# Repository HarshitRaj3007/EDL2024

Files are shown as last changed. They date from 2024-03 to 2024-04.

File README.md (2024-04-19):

# EDL2024
Repository for our EDL project in year 2024. RRAM Characterization using FPGA.

This repository contains the PCB design files of all the three modules (Main PCB, Resisitive crossbar array, Power PCB), HDL code, Python code used for GUI, and PCB enclosure design files.

There are 3 files for documentation:
1. Documentation for programming, laptop-FPGA interface & GUI
2. Documentation for PCB
3. Documentation for Testing(mainly Analog)

**HDL files**: EDL_merged_code encapsulates all the HDL code and the .py files for GUI. folder has a readme file that holds detailed information about the directory.

**PCB files**: MiniCircuit contains KiCAD files for a scaled-down version of the PCB intended for testing, FinalCircuit contains design files of the main PCB module, ResistiveCrossbar contains design files for a 3 $\times$ 3 resistive crossbar array and PowerConverter has the design files for the power PCB which was intended to power the entire module from wall supply of 230 V AC. 

**CAD files**: A basic PCB enclosure which can be fabricated via laser cutting can be found in the Enclosure_Fusion360.dxf file. Couldn't add the .stp file for the reference 3D design of the complete circuit due to file size restrictions in GitHub. 

**Operating Procedure**

Since the power PCB module we designed turned out to be faulty, we had to use power banks instead to supply $\pm$ 5 V, which have to connected appropriately to the corresponding pins in the main PCB module. The final design is highly user-friendly and all one needs to do after this step is to provide the parameters under which the characterization is to be executed: amplitude of the input pulse, the location of the resistor in the array, the mode of operation (RD/WR) and the requisite $R_{sense}$ location. The GUI displays both the input and output waveform for a pulse width of 100 $\mu s$, along with the estimated value of the resistance.

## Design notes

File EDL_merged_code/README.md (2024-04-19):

EDL 2024 P16-MON-08
 An FPGA-instrument for RRAM characterization
with on-board oscilloscope

Documentation 
for programming, laptop-FPGA interface & GUI

-Deshpande Varad Shailesh
(for whole S/W)
-21d070024

-Harshit Raj(for GUI) 
20d070033

Salient Features:
Microsecond pulsing: Square pulse as small as 100us can be achieved
ADC sampling happens at a rate around 80-100 ksps (kilo samples per second)
Communication of FPGA with laptop happens through the same USB cable used to dump code from laptop to FPGA and no other modules are required. 
A GUI on which pulse value, resistor selection and R_sense selection can be carried out. Upon hitting the send button, all necessary signals are sent out to the board, which returns the voltage waveforms for V1 and V2; These are, in turn, displayed along with the calculated value of resistance. 
Future scope: Can very easily implement pulse width value selection and intelligent R_sense selection since we have kept provisions in place for these.

Code structure:
	Entire code is essentially contained in these 5 parts
EDL_merged_code.v: The file that implements driver for Intel Avalon interface to initiate uart jtag communication with laptop and instantiates the entity for ADC & DAC.
ADC_DAC_control.vhd: This file has drivers for ADC(MCP3008) and DAC(MCP4921) and also the control logic for storing samples from the ADC, receiving square wave amplitude to the DAC.
uart_jtag(folder): This has Intel’s IPs for the avalon interface. Cannot be changed directly, any manipulation is performed through the entity declared in the .qsys file.
New_gui.py: Running this file launches the GUI.
helper.py: To encode the chosen resistor in the network into control signals to be sent to the FPGA.

Some important points to note:
Quartus needs to be installed on the device and dumping of .sof file from the computer to the FPGA must be sorted. The device must have any latest version of python installed and the Intel jtag uart python wrapper installed : https://pypi.org/project/intel-jtag-uart/, credits to Tom Verbeure.
Everytime before running the setup, the .sof file needs to be dumped from the Programmer in Quartus to the FPGA by pressing the ‘Start button’. Once this is done, the GUI can be launched after ensuring that the power supply to the PCB is at proper values of +5 and -5V. This needs to be done for performing every experiment. This is because there is some problem in resetting the FSM to the initial state, and requires some debugging the state 130;
The current code sends out a square wave to have ease of visualization, this can be changed to send a pulse by suitably modifying code in ADC_DAC_control.vhd
Provision has been made to send a pulse width from the laptop to the FPGA with proper encoding in the FSM. Changes would be required to be made in new_gui.py and both the HDL files.
Functionality for -5V reset has been provided on PCB and in the code, but needs to be tested, and would involve sending +9V and -5V to the 4066 switches on board the PCB.

Reason why minor things remain to be given a final touch:
Honestly, I feel looking back that it was way too much work for one person. Especially since programming an FPGA is generally more challenging than programming a microcontroller and that I have very little experience working with a physical FPGA. I was not familiar with verilog and had to learn this on the go. Intel’s IP files were in verilog and to implement the driver in vhdl, I would anyway need to experiment with verilog, and since attempts at doing this in vhdl failed, I had to:
Learn verilog on the go
Write driver for Intel Avalon interface in verilog while experimenting with how it worked
Since the drivers for ADC and DAC were already written in VHDL, I found a way to compile both .v and .vhd files together instead of writing driver files from scratch in verilog. 
Had I taken VLSI Design Lab in this 6th semester, my life would have been much much easier.

Sampling a clipped sine: something I’m very happy about. ADC samples correctly, and sends data correctly to the laptop through jtag uart.

Challenges in development:
“Every little signal, every state, every byte destined to be transferred had to be rehearsed with a dance on the on-board FPGA LEDs. I had kept a portable lab handy with a breadboard, some jumpers, a trim pot and a DMM to test my ADC, DAC codes just about anywhere, without a DSO.”

ADC(MCP3008) and DAC(MCP4921): Took me nearly 1.5 months to make reliable drivers for these. I also wrote drivers for AD5443 and ADS7223. The code might appear somewhat complicated due to its lengthiness. However, it is simple to understand with a counter depicting every clock cycle in the respective timing diagrams.
Talking to the FPGA from a laptop using the pre-existing jtag channel which is used to dump code to the FPGA. I followed this tutorial : https://tomverbeure.github.io/2021/05/02/Intel-JTAG-UART.html by Tom Verbeure, which involved writing a driver on the FPGA side that communicates with the Intel Avalon interface,and another of his guide: https://tomverbeure.github.io/2021/05/08/Write-Your-Own-C-and-Python-Clients-for-Intel-JTAG-UART-with-libjtag_atlantic.html for the python side.
The interface is very intricate and difficult to grasp. I had to spend a great deal of time experimenting with this, changing how every enable signal affected transmission and reception with every clock cycle. 
	To ensure reliability, I had to encode every byte transferred to denote its purpose or its place in the sequence. For example, a byte written from the laptop stays in the Intel avalon interface for an unknown amount of time, and the receiving end at the FPGA keeps receiving this byte for an unknown amount of time, until it changes due to transmission of a subsequent byte from laptop. To ensure that the byte being read is indeed the subsequent one and not the previous, I had to toggle the top 2 MSBs of the byte and use this information in conjunction with the knowledge of the present state in the FSM to ensure communication. This “jugaad” if you permit, had to be done due to a lack of time, lack of proper access, and guidance to the Intel Avalon interface.
Mixed synthesis of verilog and vhdl files: I had to again guess, try step-by-step these things from the basics for having a poor background in this matter. From passing a single signal to the vhdl entity instantiated in the verilog file to sending large vectors, clock and trigger signals between files.
Overall debugging: The painful feeling of realising that something was not working despite being careful. Mostly used LEDs to figure out what went wrong by mapping the signal to the LED output onboard the FPGA. Very limited information accessible at one instant, coupled with the time it took to compile the code(~1 min) made it a very lengthy process.

GUI Operating Instructions (and some points on its working):

CHECK First compile the quartus project and dump the code to FPGA using programmer
Then run new_gui.py to open the GUI. It is in the folder EDL_merged_code. It has a dependent file — helper.py which contains the logic for control signals and it should be in the same folder for the GUI to run properly. The sections to fill follow below.
Pulse amplitude (V) — The amplitude of the pulse to give out. Just write a floating point number which is at least 1.5V away from the max supply of the opamps (supplies connected to the -15V and +15V power headers). For example: 2.56
Array location (i,j) — The coordinates of the memristor/resistor to choose for programming/reading in the crossbar. Don’t fill in the brackets. For example: 2,3
Mode — To decide the mode of operation. It should be either: Read, Write or Reset. Note: for resetting, there should be a negative voltage at the -5V power header. Only Read has been tested extensively.
R Sense (2-6) — To choose which sense resistor to use (only in Read mode). Just enter an integer between 2 and 6 (both inclusive). For example: 3. The below table shows the corresponding resistance value:

R Sense
Resistance (Ω)
2
1M
3
300k
4
100k
5
30k
6
12k

Press the Send button after entering the above fields. The resistance value will be calculated in the Resistance (kOhm) field. The input and output waveforms, V1 and V2 will be plotted on the graph above the entry fields (only in Read mode will it be accurate). Note: we have accidentally swapped the labels V1 and V2 in the plot. The higher amplitude will be V1.
To re-run with new values, close the window and re-program the FPGA using the Quartus programmer. Then again run the new_gui.py file. We know it's not ideal but the FPGA code at the moment doesn’t support looping back reliably. The GUI instead does support it, in case it is to be used in the future.

Control Signals:

Controls 1 through 8 correspond to the Switches 1 through 8 as in the paper. 1 is for writing and 2 through 6 are the sense resistors. 7 and 8 are for connection to the ADC.
Controls 9A and 9B correspond to the Switch 9 in the paper. It was an SPDT switch but since we used SPST switches, we need two control signals and had to split it. 9A and 9B should always be the complement of each other. The same happens in Switch 10
VtXY corresponds to the vertical crossbar line X, and Y is either A or B, similar to the above point.
HzXY is similarly the horizontal crossbar line X, and Y is either A or B.
To choose a location say 2,3 — set Hz2A = 1 and Hz2A = Hz3A = 0, Vt1A = Vt2A = 1 and Vt3A = 0 (B will always be the complement of corresponding A). Hence, in HzXA, only one is set 1 whereas in VtXA, only one is set 0.
Read/Write and Reset is self explanatory and set 1 when doing that task.

For the FPGA connection, connect it to header GPIO 00  such that the entire FPGA lies away from the main PCB. The pins 1 and 3 in DE0-nano were read only so we had to short it to empty pins to ensure we could write on it. The exact pin mapping is given below with pin 1 shorted to pin 19 and pin 3 to pin 21 using wire on the PCB.

Note: The pins 11,12,29,30 are power and ground pins and so cannot be programmed. This is ensured in the mapping.

Due to the lack of time, PCB Lab didn’t print our silkscreen. To identify the pin 1 in the FPGA header, look at the main PCB such that the RRAM connection header and the power header are towards your side with the FPGA header towards the right. In this orientation, the above image exactly matches the FPGA headers. So the bottom right pin will be pin 1.

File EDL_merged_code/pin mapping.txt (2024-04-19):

ADC:
GPIO_033 - B12 - ch select ADC

GPIO_024 - C9 - reset_ADC
GPIO_025 - D9 - Din_ADC
GPIO_026 - E11 - Dout_ADC
GPIO_027 - E10 - CS_ADC
GPIO_028 - C11 - Sclk_ADC

DAC:
GPIO_00  - D3 - CS_DAC
GPIO_01 - C3 - LDAC_DAC
GPIO_02 - A2 - SCK_DAC
GPIO_03 - A3 - SDI_DAC
GPIO_04 - B3 - reset_DAC

MSB:
t1-something 
t2-correct
LSB:
t1-correct
t2-=MSB whole byte

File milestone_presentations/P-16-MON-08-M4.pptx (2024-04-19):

## An FPGA-Based Instrument for RRAM Characterization

EE 344 - Electronic Design Lab

Milestone 4

MON - 08

Debasish Panda [21d070021]
Deshpande Varad Shailesh [21d070024]

Grampurohit Shreyas Jayant [21d070029]
Harshit Raj [20d070033]

## Project Summary

We present a compact, FPGA-based implementation for characterizing RRAM (Resistive Random Access Memory) crossbar arrays which is intended to aid researchers in their study of RRAM.
- Read capability
- Write capability
- Interface available at laptop through same USB cable

## Demo Video

Link to the demo video - Demo (https://drive.google.com/drive/folders/1pQi-J_PCMW7gSlmyvDTKhVnrJv0H3NYU?usp=drive_link)

## Methodology

PCB Design and print

Design simplified circuit

Breadboard, test

Graphical User Interface

Understand reference Analog Design

[jtag uart] FPGA & Laptop link

DAC, ADC drivers

Final Circuit Design

PCB Design and print

Breadboard, test

CAD

Design ideal circuit

## Challenges faced and their solutions

Challenges | Solutions | Remarks
MAX4737 not dual supply | CD4066 | Successful
Only SPST switches but needed SPDT as well | Connected two in parallel and gave opposite control signals | Successful
DAC ESD issue | Use different DAC | Successful
ADC damage | ESD damage or excessive voltage sent during testing | Unsuccessful
100 kHz input on THT resistor lead to slewing output (like RC circuit) | Used SMD resistors to reduce capacitance, but it still had the issue | Unsuccessful
Negative voltage supply issue | External power bank | Successful
Designed a –1/2 gain instead of a +1/2 requirement in Simplified PCB | Changed the design in the Final PCB | Successful

## Challenges faced and their solutions

LM6172 OpAmp IC overheating on Simplified PCB | Searched for shorting issues | Unsuccessful
Footprint of RRAM IC wasn’t known | Made the design modular by providing a header output | Successful
Short in a trace with the ground plane in printed Final PCB | Searched for it under a microscope and cut it | Successful
Two header pins of FPGA routed on PCB were read only | Shorted it with unassigned header pins | Successful
Xen10 real time communication issue and lack of header pins | Used DE0-Nano | Successful
DE0-Nano UART JTAG/array issue | Limited documentation, very few resource online | Successful

## Examples of problems solved

- PCB trace issue: While verifying if a soldered component was connected properly by doing a shorting test, we found out that an entire trace was shorted to the ground plane. We searched for this under a microscope and found the short (refer image). This short was then cut using a knife to resolve the issue.
- Switch supplies: The switches used by us needed control signals with its Vss as reference, but our FPGA could only output between 0 and 3.3V. To ensure –5V passes through it due to device specifications and also have reliable switching, we had to power it using Vss = –5V and Vdd = +9V. This was ascertained through extensive experimentation.
- jtag uart: Intel Avalon interface is complicated, therefore to understand the reverse-engineered method, fastest way is to experiment extensively.

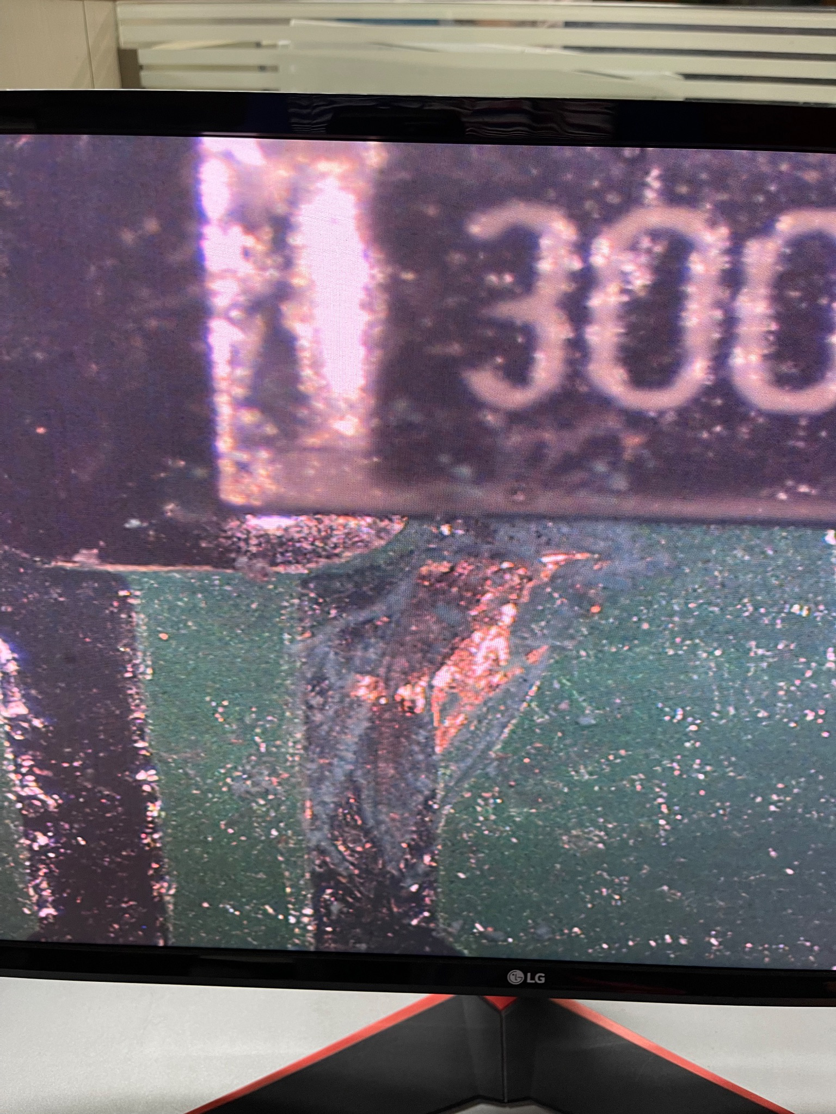
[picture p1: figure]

## Individual Contributions

Member | Contributions made over entire duration of project | Average hours spent on EDL per week in Jan and Feb ‘24 | Average hours spent on EDL per week in March and April ‘24
Shreyas | Analog Design, breadboard testing, soldering, PCB testing, GUI | 7 | 15
Harshit | PCB Design, Analog Design, breadboard testing, soldering, PCB testing | 5 | 15
Varad | FPGA: Drivers for ADC & DAC, jtag uart reverse-engineering, elementary Analog analysis | 7 | 25
Debasish | CAD, testing of procured ICs, soldering, power PCB design & testing | 4 | 12

## Conclusion

- Key functionalities demonstrated: Reading and Writing the RRAM. Resistor value has an error upto 5%. Any pulse width greater than 100 μs can be sent.
- Key lessons learnt:
1. Refer to ESD instructions in datasheet before handling an IC.
2. Read and understand the datasheets thoroughly before deciding components.
3. We underestimated the effort required to interface Laptop and FPGA effectively.
- Key gaps to be addressed: Wall power supply, Easy resistor value selection

Acknowledgements: Thanks to Prof. Siddharth Tallur & Prof. Veeresh Deshpande, Maheshwar sir, Ankur sir, Mangesh sir for their guidance and help and the entire WEL staff & TAs for keeping the lab open at hours outside of the normal schedule.

Links to access the project files: Github (https://github.com/HarshitRaj3007/EDL2024), GDrive (https://drive.google.com/drive/folders/1jz7nZt_loWthk-3VZ0CrprqIHT1pDG49?usp=drive_link)

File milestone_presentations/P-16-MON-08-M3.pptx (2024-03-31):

## An FPGA-Based Instrument for RRAM Characterization

EE 344 - Electronic Design Lab

Milestone 3

MON - 08

Debasish Panda [21d070021]
Deshpande Varad Shailesh [21d070024]

Grampurohit Shreyas Jayant [21d070029]
Harshit Raj [20d070033]

## Progress in last milestone

- Had completed the schematic in KiCAD for the final circuit.
- Had completed the testing of the analog part of the scaled-down circuit.
- VHDL driver for DAC was completed and ADC driver was being developed.
- Modified the tentative work distribution plan and Gantt chart outlining individual tasks to be done before each of the project milestones.

## Feedback received

1. Use recommended op-amp in front of DAC instead of the one we decided.
2. Make a common repository for all the documents and sheets associated with the project with version control.
3. Start making the interface between FPGA and laptop.
4. Update the Gantt Chart to include the time for making enclosure for PCB.

## Addressal of feedback

1. We were on the verge of ordering the recommended opamp, but we decided to get the new DAC working first. The new DAC got damaged since it was ESD sensitive but those precautions were not taken while soldering. So we decided to stay with the old DAC.
2. We have created a common Github repository - https://github.com/HarshitRaj3007/EDL2024
3. The POC for interfacing of FPGA with laptop is ready.
4. Gantt Chart has been updated accordingly.

Videos@ https://drive.google.com/drive/folders/13kLhzrZny3STd89KioyVIFqhOgMc7KOY?usp=sharing

## PCB Readiness

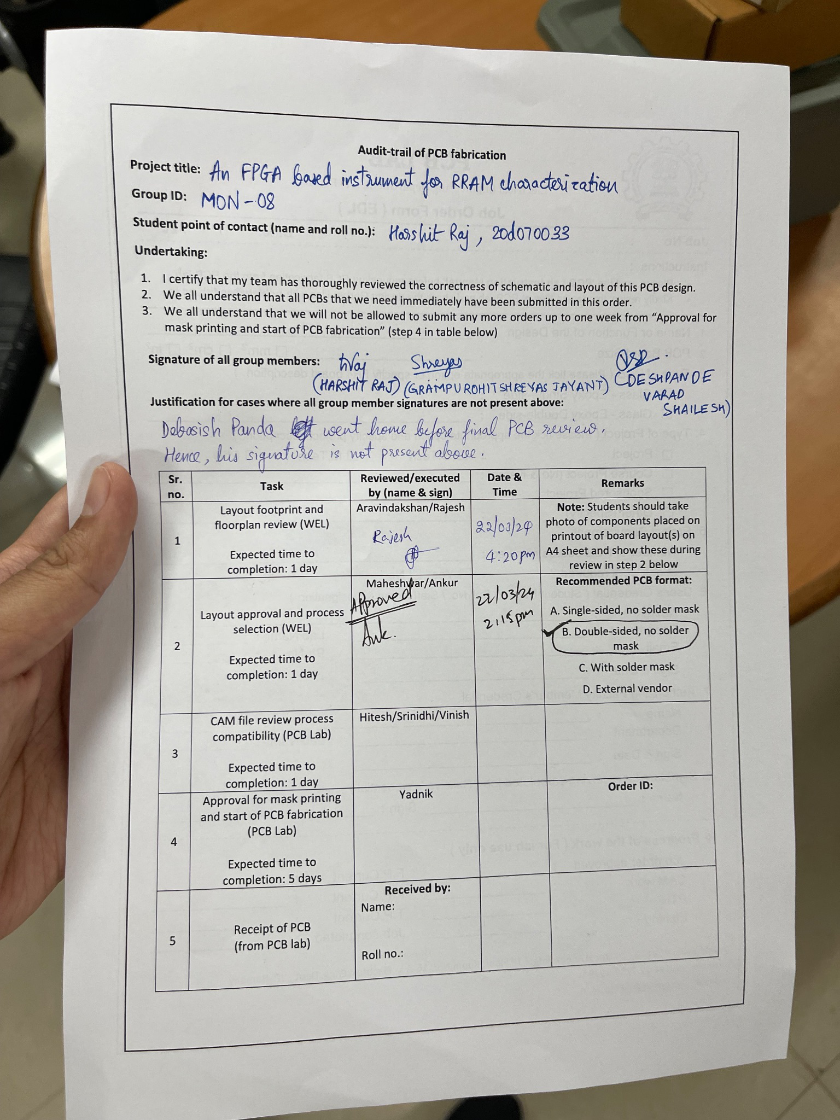
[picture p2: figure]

- PCB layout for the scaled-down version of the circuit (which will be used as a backup option) has been submitted for printing.
- PCB design of the final version is still in progress.
Note: The PCB form on the right only shows Stage 2 complete as the PCB Lab, after Stage 3 and Stage 4 verification, directly took the form when giving the order.

## CAD Readiness

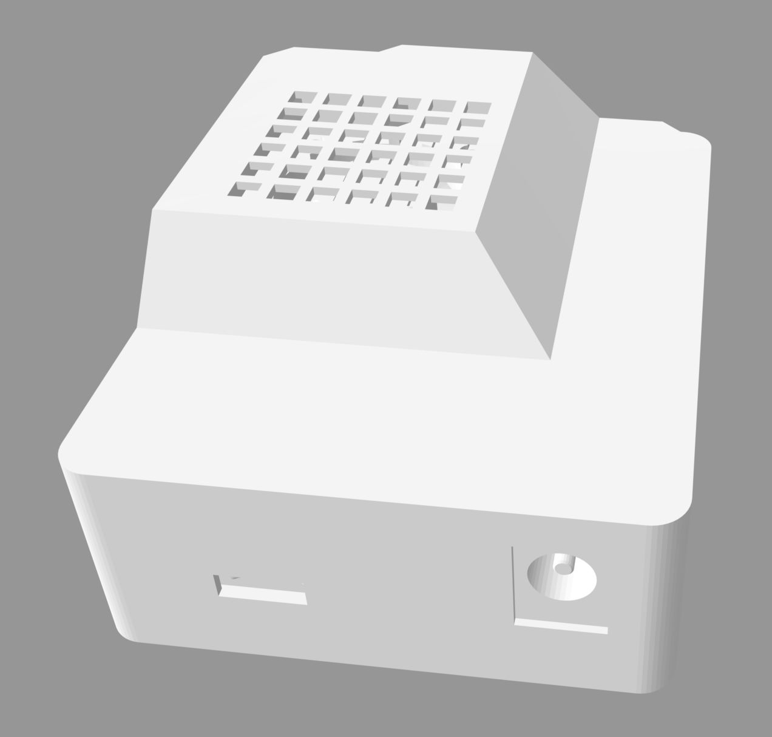
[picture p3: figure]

A preliminary design for the PCB enclosure has been completed on Fusion 360 whose geometric dimensions have not been finalised yet since we do not have the PCB layout of the final version. As soon as our PCB design is complete (will be done in 1-2 days), the CAD design will be updated accordingly.

## Critical tasks in progress

1. PCB design for the power supply circuit is in progress
2. Final PCB design is in progress
3. CAD design for PCB enclosure is in progress

## Key risks not yet addressed

1. We will receive our testing PCB on 1st April or later. If we find issues in that, we will have to shift our focus on identifying issues in the testing PCB and making it work.
2. We haven’t addressed over-current protection properly using analog circuitry, in case the RRAM has some error and becomes a dead short or gets low impedance (a coding solution has been thought of).

## Updated Gantt chart for project planning

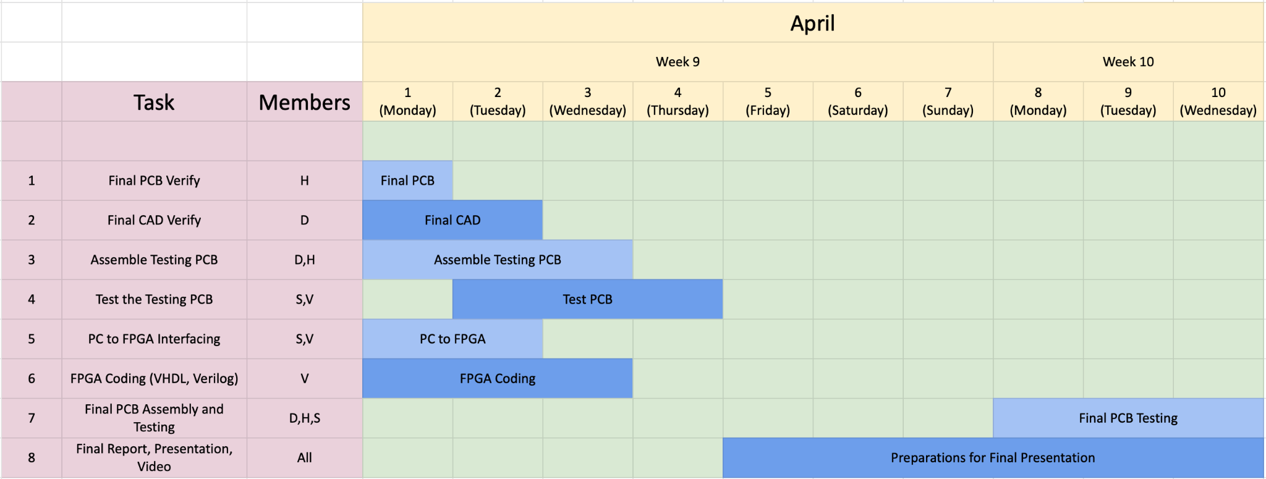
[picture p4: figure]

## Reasons for deviation from Gantt chart

1. We had not considered that 10 days in between would be spent in midsem.
2. The previous Gantt chart was too demanding and so we had to postpone a few tasks to the coming week
3. The PCB printing for the simplified version is taking much longer than expected. Few decisions and work are based upon the working of this circuit on PCB.

## Work distribution

1. Harshit: Ideal Circuit design, PCB design of Simplified Circuit, Final Circuit design, PCB design of Final Circuit.
2. Shreyas: Simplified Circuit design, Ideal Circuit design, testing of analog circuits in Simplified Circuit - breadboard, testing of analog circuits in Ideal Circuit design, design of Final Circuit, Graphical User Interface(Python).
3. Varad: Development of VHDL drivers for scaled down and powerful ADCs and DACs, development of Verilog driver to initiate UART through JTAG using Intel Avalon interface, control logic for driving the operations.
4. Debasish: Testing and verification of the procured ICs after soldering them to breakout boards for the same, CAD (PCB enclosure) design, PCB and circuit design of the Power Module.

## Final demo plans

We tried interfacing the powerful ADC with FPGA, and while it worked initially, we realised it stopped functioning in testing(prior ESD damage possibility). Since the final PCB deadline is near, we decided not to fiddle with the spare (new) ADC, and rather stick to the ADC in the simplified version. So we have decided to refine the current design. Following are the additional features we plan to present:
1. Support for -5V
2. 4 x 4 resistive crossbar array
3. We are actively working on the GUI as well.

## Planned pipeline for the final demo

- The user will see an interface on a PC to control the device. They can choose to read/write/reset the RRAM. They can provide the voltage and square pulse duration for writing, and choose the particular unit in the crossbar.
- The set parameters go to the FPGA through UART-JTAG, the switches are set in the required orientation, and the pulse is sent out using the DAC.
- The analog circuitry handles the pulse to the RRAM and the data comes back to the FPGA through the ADC.
- The FPGA sends the data back to the PC.
- The Python frontend on PC performs the required calculations and prints out the necessary information back to the user.

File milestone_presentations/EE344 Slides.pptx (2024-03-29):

## An FPGA-Based Instrument for RRAM Characterization

Debasish Panda [21d070021]
Deshpande Varad Shailesh [21d070024]

Grampurohit Shreyas Jayant [21d070029]
Harshit Raj [20d070033]

What is the problem that we are trying to solve? RRAM, or Resistive Random Access Memory, is a promising technology for the future of computing because it offers several advantages over conventional memory storage elements, such as compactness, faster speed, lower power consumption, and durability. We wish to implement an FPGA-based mechanism to characterize RRAM crossbar arrays for better understanding to enable performance optimization.

Ideal specifications as implemented in paper The paper we have been provided with has designed an FPGA-based instrument with capabilities of on-board oscilloscope and nanoscale pulsing (70 ns @ ± 10V), thus allowing exploration of the nano-scale switching capabilities of RRAM devices. The system should ideally possess less than 1% read-out error for resistance range between 1 kΩ to 1 MΩ. However, due to several practical considerations and the budget involved, we had to downscale the specifications appropriately. Detailed reasons have been provided in the subsequent slides.

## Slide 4

Design as implemented in paper[1]

- Nanoscale pulsing ability (70 ns)
- Less than 1% read-out error for resistance range between 1 kΩ to 1 MΩ
- ± 10 V voltage range
- 14-bit DAC and ADC pathways
- 32 ⤫ 32 resistive crossbar array

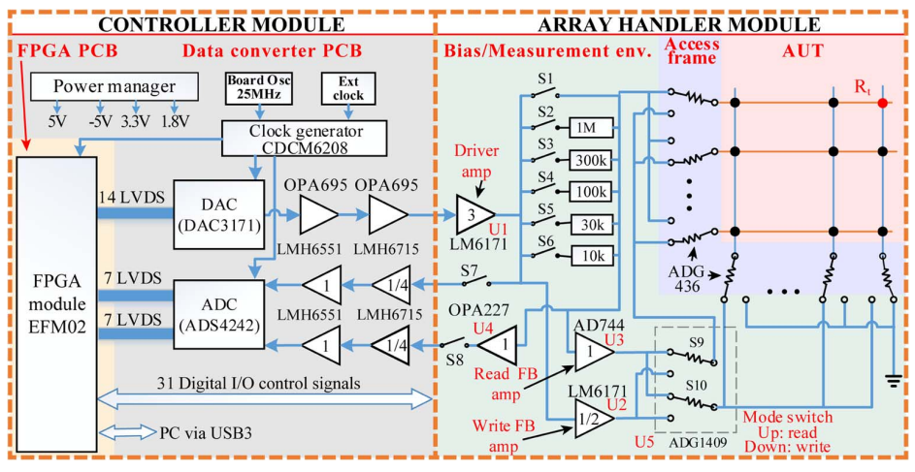
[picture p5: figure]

Simplified array control instrument diagram. The system is partitioned into a controller and an array handler module[1].

[1] Jinling Xing, Alexander Serb, Ali Khiat, Radu Berdan, Hui Xu, and Themistoklis Prodromakis, “An FPGA-Based Instrument for En-Masse RRAM Characterization With ns Pulsing Resolution”, IEEE Trans. Circuits and Systems, vol. 63, no.6, 2016

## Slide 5

Design as implemented in paper[2]

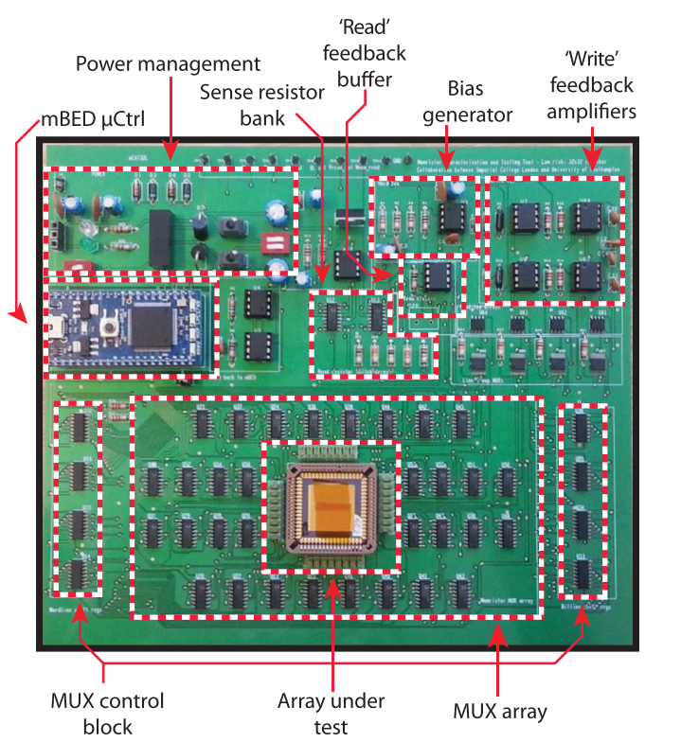
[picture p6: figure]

PCB implementation of a μ-controller-based system (mCAT) for RRAM characterization as presented in the research paper[2]. Note that we shall be using an FPGA module for characterization and interfacing instead of a μ-controller.

[2] Radu Berdan, Alexander Serb, Ali Khiat, Anna Regoutz, Christos Papavassiliou and Themis Prodromakis, “A μ-Controller-Based System for Interfacing Selectorless RRAM Crossbar Arrays”, IEEE Trans. Electron Devices, vol.62, no.7, 2015

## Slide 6

Principle of operation[1]

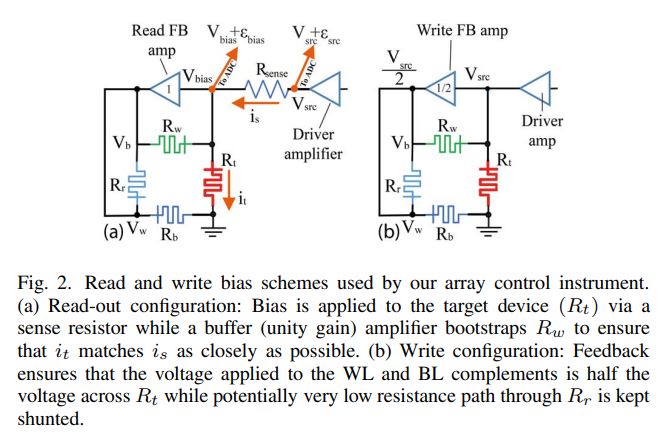
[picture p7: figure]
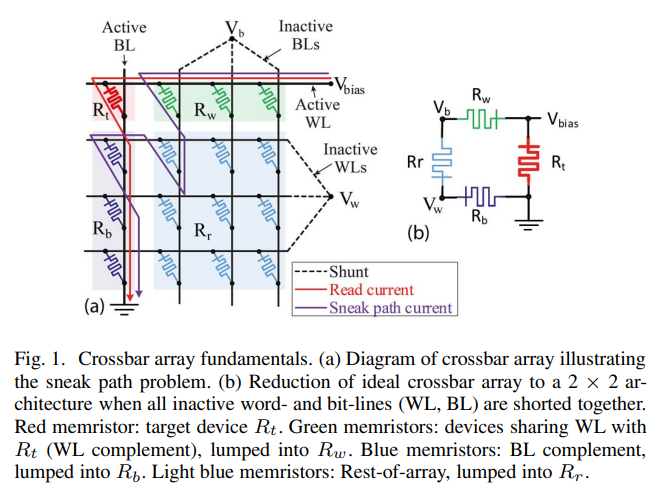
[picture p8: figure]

[1] Jinling Xing, Alexander Serb, Ali Khiat, Radu Berdan, Hui Xu, and Themistoklis Prodromakis, “An FPGA-Based Instrument for En-Masse RRAM Characterization With ns Pulsing Resolution”, IEEE Trans. Circuits and Systems, vol. 63, no.6, 2016

## Practical target specifications

- 10 μs to 100 μs pulsing capability
In order to achieve nanoscale pulsing, we would require ADC and DAC having very high sampling rate (around 50 MSPS). However, they are extremely expensive and well over the allotted budget. Further, using nanoscale pulses would cause propagation delays in the PCB. Hence, we settle with μs pulsing capability.
- ± 5 V voltage range
We reduce this range in order to be able to attain decent range of resistance values of memristors and yet not make the ADC and other components expensive.

## Practical target specifications (contd.)

- 8 ⤫ 8 resistive crossbar array
Implementation of a 32 x 32 array would require too many switches and would be difficult to implement in a 2 layer PCB.
- Resistance range between 10 kΩ and 100 kΩ
This is based on the voltage range and the pulse duration that we have decided.
- 12-bit DAC and 16-bit ADC pathways
This is to ensure a good resolution of measurement. To make measurements, we will give out a pulse of ~10 mV and 5V/0.5 mV needs ~ 12 bits.

## Value proposition

RRAM is a highly developing field with the following advantages:
- Potential to revolutionize storage: Could replace flash storage in devices like smartphones and laptops due to its speed, size, and energy efficiency.
- Emerging applications: Being explored for use in artificial intelligence (AI) and neuromorphic computing due to its ability to mimic brain functions.
- Research focus: Many companies and research institutions are actively developing RRAM technology, with significant advancements happening.
If we successfully develop a cheap implementation of RRAM characterisation it will be very helpful in multiple domains, including the ongoing research in the institute.

## Methodology

1. We will first go through the design implemented in the paper and make the necessary changes in it based on the components we have selected and the specifications we need to achieve.
2. Next, we shall start working in parallel on the VHDL implementation and the PCB design.
3. After a rigorous verification of the schematic, PCB design and the VHDL code, we will assemble the circuit and test it. We will first test on an 8 ⤫ 8 resistive crossbar array instead of using an RRAM directly.
4. Finally, after testing on the actual RRAM device, we will make an interface to display the characterisation output on to a laptop display, with the help of PicoIRIS platform if needed.

## Choice of components

- Amplifiers: The current we need to measure is of the order of nA, and thus even a small noise in any signal would disrupt the readings. Further, the pulses have a duration of the order of μs, hence we need low noise, high-speed amplifiers, although they are pretty expensive
- ADC & DAC: We need a differential input, dual channel 16 bit ADC with at least 1Msps ADC. For the 12 bit DAC, we need a current-output, rise/fall times ~ ns to get a sharp pulse output for programming the RRAM.
- FPGA module: The Xen-10 board available in the WEL lab operated at 50MHz seems sufficient for our task.
- Switches: MAX4737 which has off current is ~nA, fast switching ~ns, can sustain ~10V across it in open configuration - matching the specifications for our design. This is available in WEL Lab.

## Power considerations

- Aim: To power a) Xen 10 board b) our PCB with 5V
- Usage: Li-ion battery from WEL. We will use a battery protection charger module(TP5100) to safeguard our circuit. A dc barrel jack will be used to plug into the PCB.
- We will use Voltage regulator ICs(5V: LM7805, 3.3V:LM1117, 1.8V: LM1117)

## Gantt chart for project planning

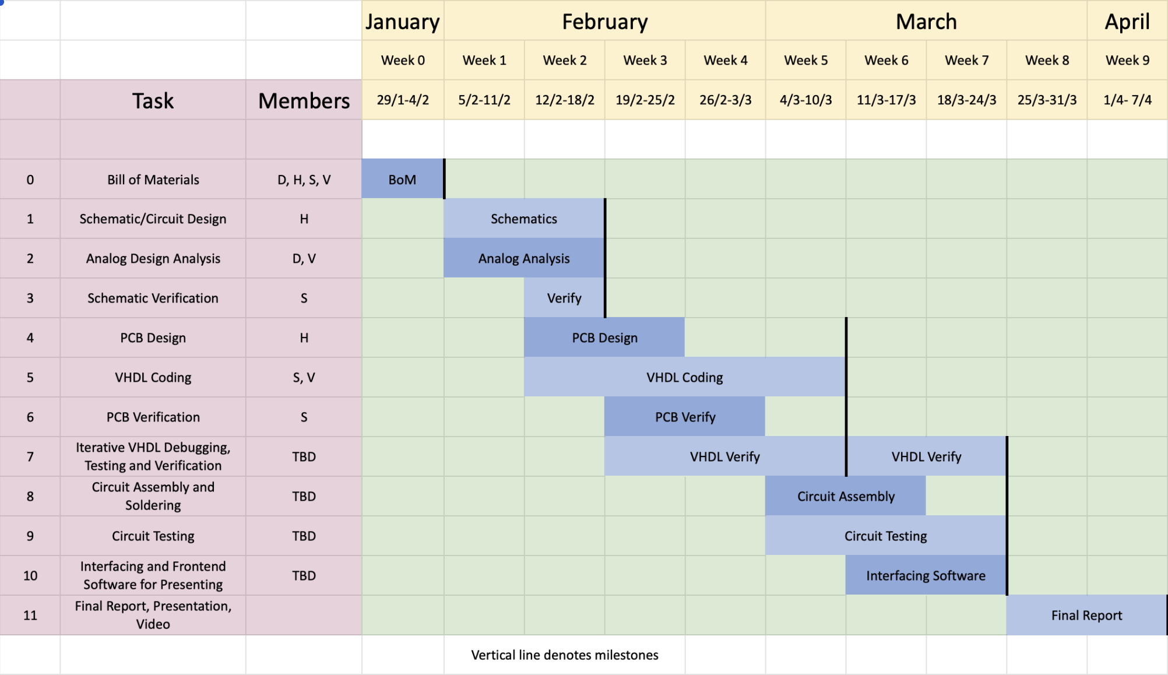
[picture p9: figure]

D-Debasish, H-Harshit, S-Shreyas, V- Varad

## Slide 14

Work distribution across team members
- VHDL coding - Shreyas & Varad
- PCB design - Harshit & Shreyas
- Analog design - Debasish & Varad
- Heat management in PCB - Debasish
- Resistive crossbar prototype for RRAM - Harshit
- Interfacing and frontend software - optional; whomever among Shreyas, Varad & Harshit finishes first will take up this task
- VHDL debugging - Any two members
- Circuit assembly & soldering - Same two members as involved in VHDL debugging

Week-wise goals
- Week 0 - Bill of Materials
- Week 1 - Schematic design + Analog design
- Week 2 - Schematic design + Circuit design + Schematic verification + PCB design + VHDL coding
- Week 3 - PCB design + VHDL coding + PCB verification + VHDL debug
- Week 4 - VHDL coding + PCB verification + VHDL debug
- Week 5 - VHDL coding + VHDL debug + Circuit assembly + Circuit testing
- Week 6 - VHDL debug + Circuit assembly + Circuit testing + GUI
- Week 7 - VHDL debug + Circuit testing + GUI
- Week 8 - Final report
- Week 9 - Final report

## Key risks and mitigation strategies

1. Cost & Analog design: The design presented in the paper is an expensive high-speed, precision design. Due to cost (primarily of DAC and ADC) we cannot replicate it directly, and the challenge lies in a) identifying usage of every component b) finding a suitable alternative that matches specifications. Solution: Cumulative cost of op-amps used in the paper are not as costly as the ADC (~30k) and we can directly use them to preserve the design ideals and find ADC & DAC with a lesser sampling rate.
2. PCB Design: To support μs pulsing and have small track lengths to avoid delays.
3. Heat management: Given that the PCB has multiple components, heat management is a major cause of concern. Solution: Appropriate analysis will be done after PCB design to improve heat dissipation in the PCB.
4. Soldering SMD: None of the team members have any decent experience with soldering and it will take some guidance from faculty and staff to teach us the same.

## Deliverables (expected outcomes of the project)

- Functional board that is an economical replication of the prototype presented in the paper.
- To develop a user-friendly frontend application for the board, with the picoIRIS platform as a reference.

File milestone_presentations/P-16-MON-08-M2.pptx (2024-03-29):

## An FPGA-Based Instrument for RRAM Characterization

EE 344 - Electronic Design Lab

Milestone 2

MON - 08

Debasish Panda [21d070021]
Deshpande Varad Shailesh [21d070024]

Grampurohit Shreyas Jayant [21d070029]
Harshit Raj [20d070033]

## Progress in last milestone

- Identified and understood the problem statement that we’re working on along with practically achievable target specs for our proposed implementation.
- Identified suitable components for on-board implementation of the circuit after going through multiple datasheets and the prescribed research papers so as to ensure an economically viable project, while achieving satisfactory specifications.
- Tentative work distribution plan and Gantt chart outlining individual tasks to be done before each of the project milestones.

## Feedback received

1. The initial ideation was to power our implementation by a battery source, which was pointed out to be less favourable for extended running times, and we were asked to make provision for the board to be powered via A/C supply.
2. We were also asked to make a simpler, scaled-down version of the final implementation, using components available at WEL as a backup option.

## Addressal of feedback

1. We scrapped the idea of using batteries as a power source, and decided instead to use an A/C adapter so as to power the board using domestic A/C supply, while enumerating all the power management considerations. These power management concerns have been taken into consideration in the schematic.
2. To achieve the scaled down implementation, we have three major subtasks:
- Analog Design considerations
  - Elementary testing of the scaled-down version of the analog circuit has been completed. No sneak currents were observed and resistance values were obtained accurately, even for 5 μs pulse. In some cases, there was propagation delay and slew rate issues, which are expected to reduce once the improved components arrive.
- ADC and DAC interfacing
  - Except for some minor issues, we were able to read data from both ADC testing circuit. For DAC, we are able to send the expected SPI signal from FPGA but facing some issues with getting the output from DAC. Most importantly, the VHDL simulation of the code was as per our expectations.
- Schematic and PCB
  - Schematic has been completed and we are currently working on the PCB layout.

## Updated Gantt chart for project planning

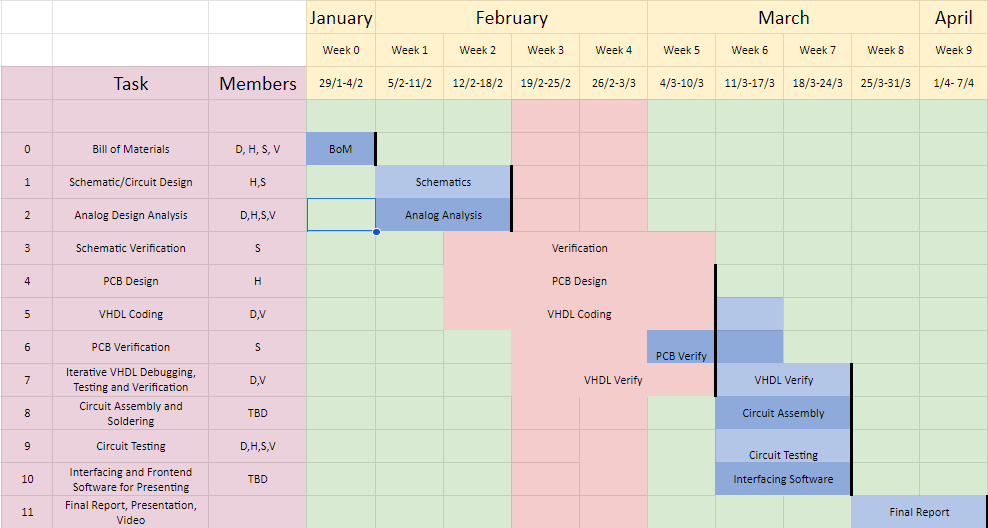
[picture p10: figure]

Weeks 3 and 4 are mid-semester weeks

## Reasons for deviation from Gantt chart

When we initially made the chart, we did not realise that mid-semesters were scheduled from 24th Feb to 2nd March. This caused some tasks after Milestone 1 to be shifted towards the right side.

## Block diagram

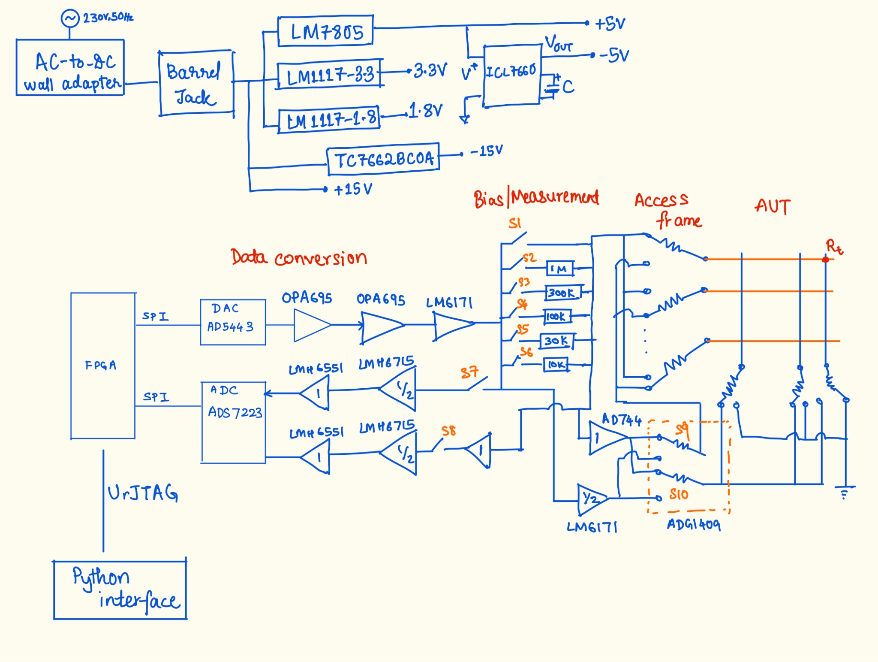
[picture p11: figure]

## Calculations and analysis for block diagram

- Power supply: These considerations are based on the various requirements of amplifiers, switches, ADC and DAC.
- DAC Pathway:
  - OPA695s are CFAs. The output of OPA695 pair is from -4.2V to 4.2V. But at the output of LM6171 the output range is -5V to 5V. Hence the gain of LM6171 is set to 1.19.
- ADC Pathway:
  - LMH6715 is set to a gain of 0.5 so that the input voltage at the ADC lies within the range of -2.5V to 2.5V.
Detailed calculations and reasoning for selection of particular resistance and capacitance values, along with the type of configuration of amplifiers, etc will be explained in a report.

## Circuit Schematic

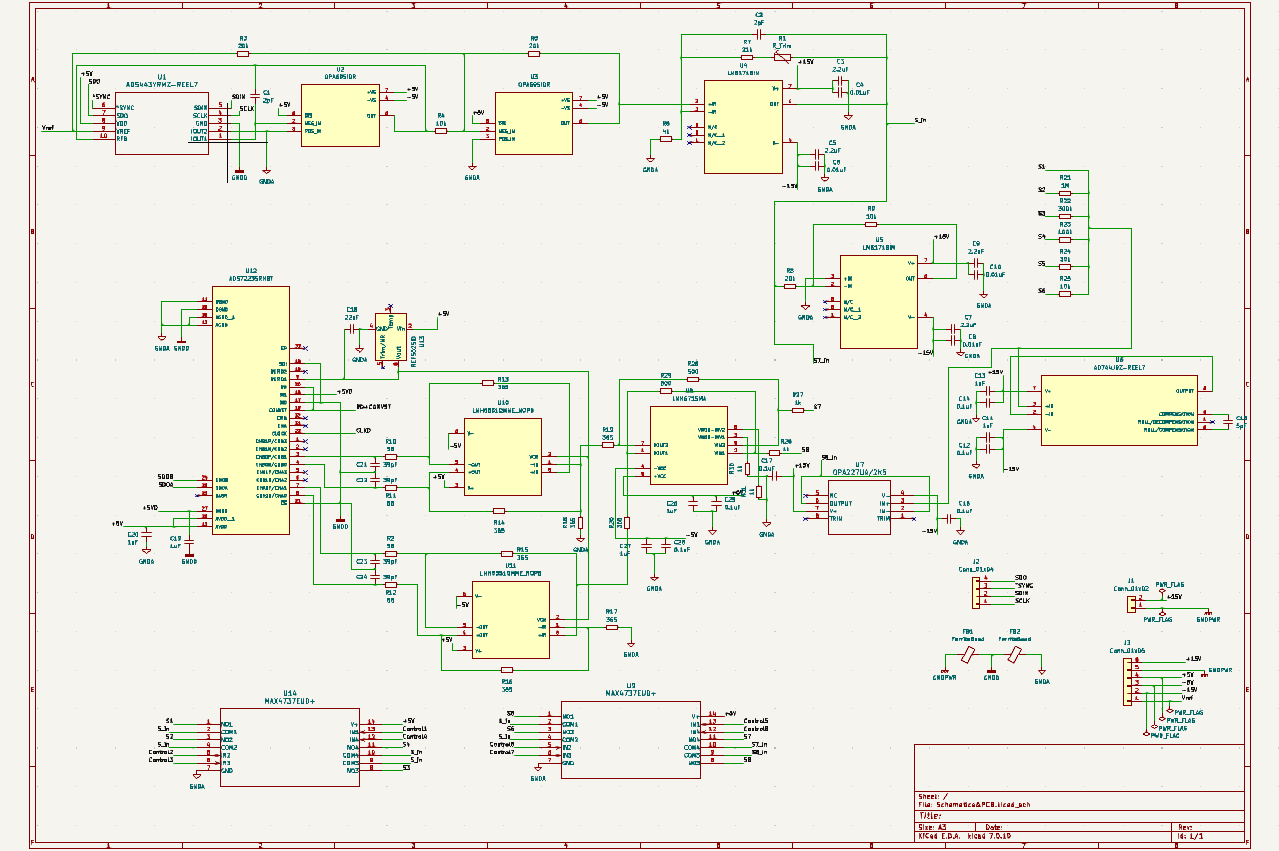
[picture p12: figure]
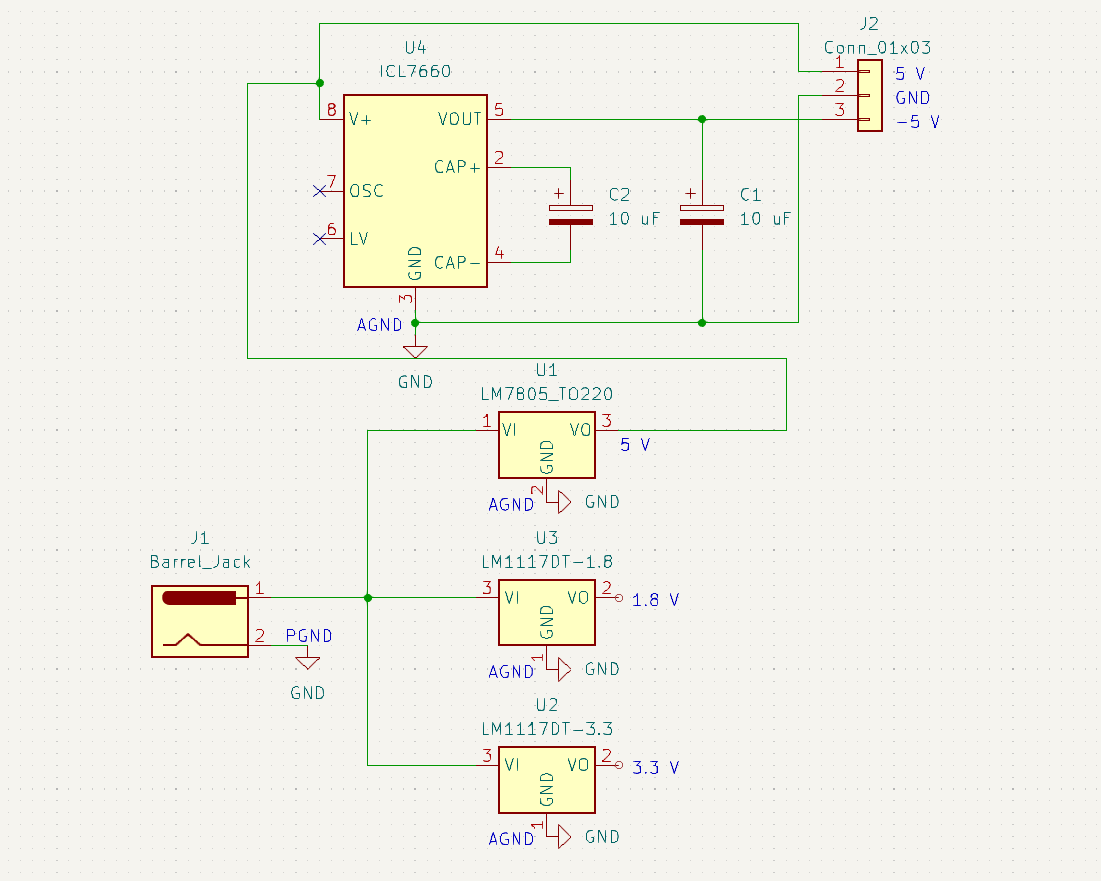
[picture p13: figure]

## Testing plan

- Preliminary testing
  - Testing of analog circuits for the scaled-down version has been completed.
  - Testing of ADC-FPGA interface has been nearly completed, and the testing of the DAC-FPGA interface is in progress.
- Intermediate testing
  - Next up, we’ll be testing the analog circuits using the actual components ordered for the project on breakout boards. Another significant change we aim to introduce in this phase is to power the chips using A/C supply as recommended to us.
  - Similarly, we’ll be testing the ADC and DAC interface with the new components and try to increase the extent of testing by actually interfacing the ADC and DAC with the verified analog circuits.
  - As soon as our ordered components arrive, we can test them on breakout boards (for VQFN-32, SOIC-8, MSOP-10 are available, we have checked the same with Maheshwar Sir).
- Final testing
  - The final stage will involve verification of the PCB layout (packaged within an enclosure box) which will be tested while being powered by domestic A/C supply.

## Results of preliminary testing

- The resistance value inside the 2 x 2 array used for testing was estimated accurately up to the third decimal point.
- No sneak currents were seen.
- The resistance measurement was accurate even for a pulse of 5 μs. This implies that the amplifiers selection in the testing circuit based on slew rate, bandwidth and other considerations was correct.
- The ADC is able to correctly send data and as shown in the video, we have checked the waveforms on the DSO, there is a minor problem in displaying this onto the FPGA LEDs. For the DAC, we are able to generate the correct command sequence through SPI.

## Additional Considerations

1. PCB printing
Our project needs VQFN-32, MSOP-10, SOIC-8 packages, which we have checked with Maheshwar Sir, and are workable with in our lab itself. We can order from PCB power if, in some unseen scenario, we need to outsource.
We have checked with the lab, and there are breakout boards available to test each of these.
1. User interface
Thought of a simple python-driven interface or a webpage that dumps data into a .txt file, and this will communicate with the FPGA via a urJTAG interface.

## Additional Considerations (contd.)

3. PCB Holder/Enclosure
We are working on creating a mechanical holder/enclosure for the PCB. We have learnt the basics of CAD software and will soon start working on it once major tasks are accomplished.

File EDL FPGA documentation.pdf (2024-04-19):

# EDL 2024 P16-MON-08

## An FPGA-instrument for RRAM characterization with on-board oscilloscope

## Documentation

for programming, laptop-FPGA interface & GUI
- Deshpande Varad Shailesh (for whole S/W)
21d070024
- Harshit Raj and Grampurohit Shreyas Jayant (for GUI) 20d070033 and 21d070029

Salient Features:
1. Microsecond pulsing: Square pulse as small as 100us can be achieved
2. ADC sampling happens at a rate around 80-100 ksps (kilo samples per second)
3. Communication of FPGA with laptop happens through the same USB cable used to dump code from laptop to FPGA and no other modules are required.
4. A GUI on which pulse value, resistor selection and R_sense selection can be carried out. Upon hitting the send button, all necessary signals are sent out to the board, which returns the voltage waveforms for V1 and V2; These are, in turn, displayed along with the calculated value of resistance.
5. Future scope: Can very easily implement pulse width value selection and intelligent R_sense selection since we have kept provisions in place for these.

Code structure:
Entire code is essentially contained in these 5 parts
1. EDL_merged_code.v: The file that implements driver for Intel Avalon interface to initiate uart jtag communication with laptop and instantiates the entity for ADC & DAC.
2. ADC_DAC_control.vhd: This file has drivers for ADC(MCP3008) and DAC(MCP4921) and also the control logic for storing samples from the ADC, receiving square wave amplitude to the DAC.
3. uart_jtag(folder): This has Intel’s IPs for the avalon interface. Cannot be changed directly, any manipulation is performed through the entity declared in the .qsys file.
4. New_gui.py: Running this file launches the GUI.
5. helper.py: To encode the chosen resistor in the network into control signals to be sent to the FPGA.

Some important points to note:
1. Quartus needs to be installed on the device and dumping of .sof file from the computer to the FPGA must be sorted. The device must have any latest version of python installed and the Intel jtag uart python wrapper installed : https://pypi.org/project/intel-jtag-uart/, credits to Tom Verbeure. (https://tomverbeure.github.io/)
2. Everytime before running the setup, the .sof file needs to be dumped from the Programmer in Quartus to the FPGA by pressing the ‘Start button’. Once this is done, the GUI can be launched after ensuring that the power supply to the PCB is at proper values of +5 and -5V. This needs to be done for performing every experiment. This is because there is some problem in resetting the FSM to the initial state, and requires some debugging the state 130;
3. The current code sends out a square wave to have ease of visualization, this
can be changed to send a pulse by suitably modifying code in ADC_DAC_control.vhd
4. Provision has been made to send a pulse width from the laptop to the FPGA with proper encoding in the FSM. Changes would be required to be made in new_gui.py and both the HDL files.
5. Functionality for -5V reset has been provided on PCB and in the code, but needs to be tested, and would involve sending +9V and -5V using the

### Power PCB made by

Debasish Panda(21d070021)
to the 4066 switches on board the PCB.

Reason why minor things remain to be given a final touch:
Honestly, I feel looking back that it was way too much work for one person. Especially since programming an FPGA is generally more challenging than programming a microcontroller and that I have very little experience working with a physical FPGA. I was not familiar with verilog and had to learn this on the go. Intel’s IP files were in verilog and to implement the driver in vhdl, I would anyway need to experiment with verilog, and since attempts at doing this in vhdl failed, I had to:
a. Learn verilog on the go
b. Write driver for Intel Avalon interface in verilog while experimenting with how it worked Since the drivers for ADC and DAC were already written in VHDL, I found a way to compile both .v and .vhd files together instead of writing driver files from scratch in verilog.
Had I taken VLSI Design Lab in this 6th semester, my life would have been much much easier.

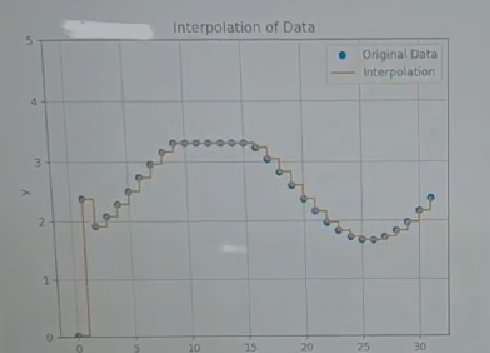
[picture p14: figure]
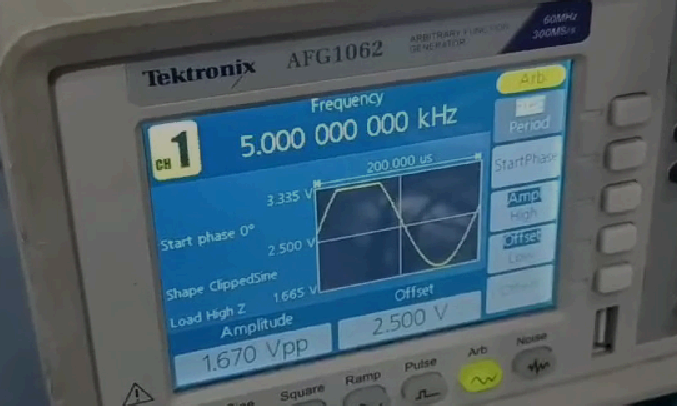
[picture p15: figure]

Sampling a clipped sine: something I’m very happy about. ADC samples correctly, and sends data correctly to the laptop through jtag uart.

GUI Operating Instructions (and some points on its working):

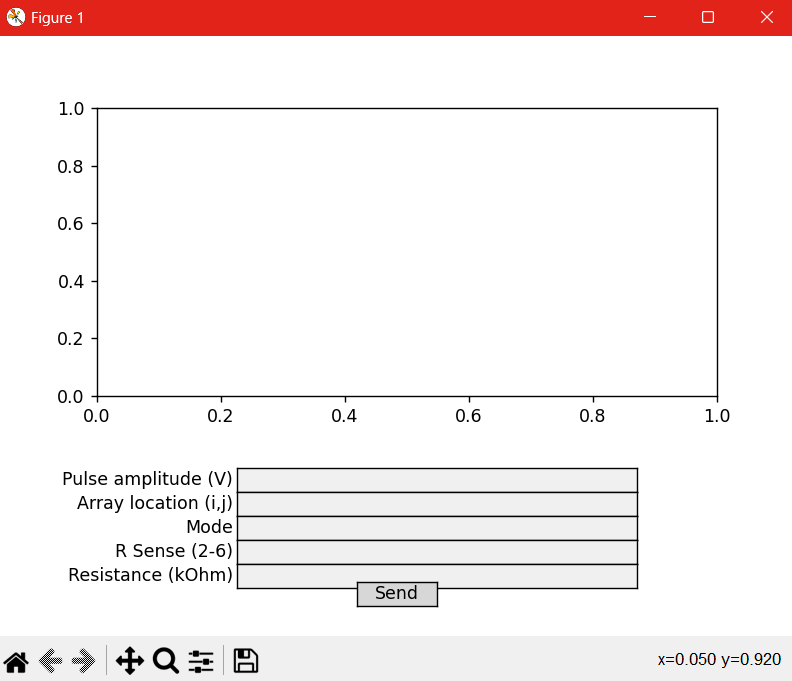
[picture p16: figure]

1. CHECK First compile the quartus project and dump the code to FPGA using programmer
2. Then run new_gui.py to open the GUI. It is in the folder EDL_merged_code. It has a dependent file — helper.py which contains the logic for control signals and it should be in the same folder for the GUI to run properly. The sections to fill follow below.
3. Pulse amplitude (V) — The amplitude of the pulse to give out. Just write a floating point number which is at least 1.5V away from the max supply of the opamps (supplies connected to the -15V and +15V power headers). For example: 2.56
4. Array location (i,j) — The coordinates of the memristor/resistor to choose for programming/reading in the crossbar. Don’t fill in the brackets. For example: 2,3

5. Mode — To decide the mode of operation. It should be either: Read, Write or Reset. Note: for resetting, there should be a negative voltage at the -5V power header. Only Read has been tested extensively.
6. R Sense (2-6) — To choose which sense resistor to use (only in Read mode). Just enter an integer between 2 and 6 (both inclusive). For example: 3. The below table shows the corresponding resistance value:
R Sense | Resistance (Ω)
2 | 1M
3 | 300k
4 | 100k
5 | 30k
6 | 12k
7. Press the Send button after entering the above fields. The resistance value will be calculated in the Resistance (kOhm) field. The input and output waveforms, V1 and V2 will be plotted on the graph above the entry fields (only in Read mode will it be accurate). Note: we have accidentally swapped the labels V1 and V2 in the plot. The higher amplitude will be V1.
8. To re-run with new values, close the window and re-program the FPGA using the Quartus programmer. Then again run the new_gui.py file. We know it's not ideal but the FPGA code at the moment doesn’t support looping back reliably. The GUI instead does support it, in case it is to be used in the future.

### Challenges in development:

“Every little signal, every state, every byte destined to be transferred had to be rehearsed with a dance on the on-board FPGA LEDs. I had kept a portable lab handy with a breadboard, some jumpers, a trim pot and a DMM to test my ADC, DAC codes just about anywhere, without a DSO.”

1. ADC(MCP3008) and DAC(MCP4921): Took me nearly 1.5 months to make reliable drivers for these. I also wrote drivers for AD5443 and ADS7223. The code might appear somewhat complicated due to its lengthiness. However, it is simple to understand with a counter depicting every clock cycle in the respective timing diagrams.
2. Talking to the FPGA from a laptop using the pre-existing jtag channel which is used to dump code to the FPGA. I followed this tutorial : https://tomverbeure.github.io/2021/05/02/Intel-JTAG-UART.html by Tom Verbeure, which involved writing a driver on the FPGA side that communicates with the Intel Avalon interface,and another of his guide: https://tomverbeure.github.io/2021/05/08/Write-Your-Own-C-and-Python-Clients-for-Intel-JTAG-UART-with-libjtag_atlantic.html (https://tomverbeure.github.io/2021/05/08/Write-Your-Own-C-and-Python-Clients-for-Intel-JTAG-UART-with-libjtag_atlantic.html) for the python side.
The interface is very intricate and difficult to grasp. I had to spend a great deal of time experimenting with this, changing how every enable signal affected transmission and reception with every clock cycle.
To ensure reliability, I had to encode every byte transferred to denote its purpose or its place in the sequence. For example, a byte written from the laptop stays in the Intel avalon interface for an unknown amount of time, and the receiving end at the FPGA keeps receiving this byte for an unknown amount of time, until it changes due to transmission of a subsequent byte from laptop. To ensure that the byte being read is indeed the subsequent one and not the previous, I had to toggle the top 2 MSBs of the byte and use this information in conjunction with the knowledge of the present state in the FSM to ensure communication. This “jugaad” if you permit, had to be done due to a lack of time, lack of proper access, and guidance to the Intel Avalon interface.
3. Mixed synthesis of verilog and vhdl files: I had to again guess, try step-by-step these things from the basics for having a poor background in this matter. From passing a single signal to the vhdl entity instantiated in the verilog file to sending large vectors, clock and trigger signals between files.
4. Overall debugging: The painful feeling of realising that something was not working despite being careful. Mostly used LEDs to figure out what went wrong by mapping the signal to the LED output onboard the FPGA. Very limited information accessible at one instant, coupled with the time it took to compile the code(~1 min) made it a very lengthy process.

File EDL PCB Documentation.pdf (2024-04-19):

# EDL 2024 P16-MON-08

## An FPGA-instrument for RRAM characterization with on-board oscilloscope

## Documentation for PCB

- Harshit Raj
20d070033

Control Signals:

1. Controls 1 through 8 correspond to the Switches 1 through 8 as in the paper. 1 is for writing and 2 through 6 are the sense resistors. 7 and 8 are for connection to the ADC.
2. Controls 9A and 9B correspond to the Switch 9 in the paper. It was an SPDT switch but since we used SPST switches, we needed two control signals and had to split it. 9A and 9B should always be the complement of each other. The same happens in Switch 10
3. VtXY corresponds to the vertical crossbar line X, and Y is either A or B, similar to the above point.
4. HzXY is similarly the horizontal crossbar line X, and Y is either A or B.
5. To choose a location say 2,3 — set Hz2A = 1 and Hz2A = Hz3A = 0, Vt1A = Vt2A = 1 and Vt3A = 0 (B will always be the complement of corresponding A). Hence, in HzXA, only one is set 1 whereas in VtXA, only one is set 0.
6. Read/Write and Reset is self explanatory and set 1 when doing that task.

For the FPGA connection, connect it to header GPIO 00 such that the entire FPGA lies away from the main PCB. The pins 1 and 3 in DE0-nano were read only so we had to short it to empty pins to ensure we could write on it. The exact pin mapping is given below with pin 1 shorted to pin 19 and pin 3 to pin 21 using wire on the PCB.

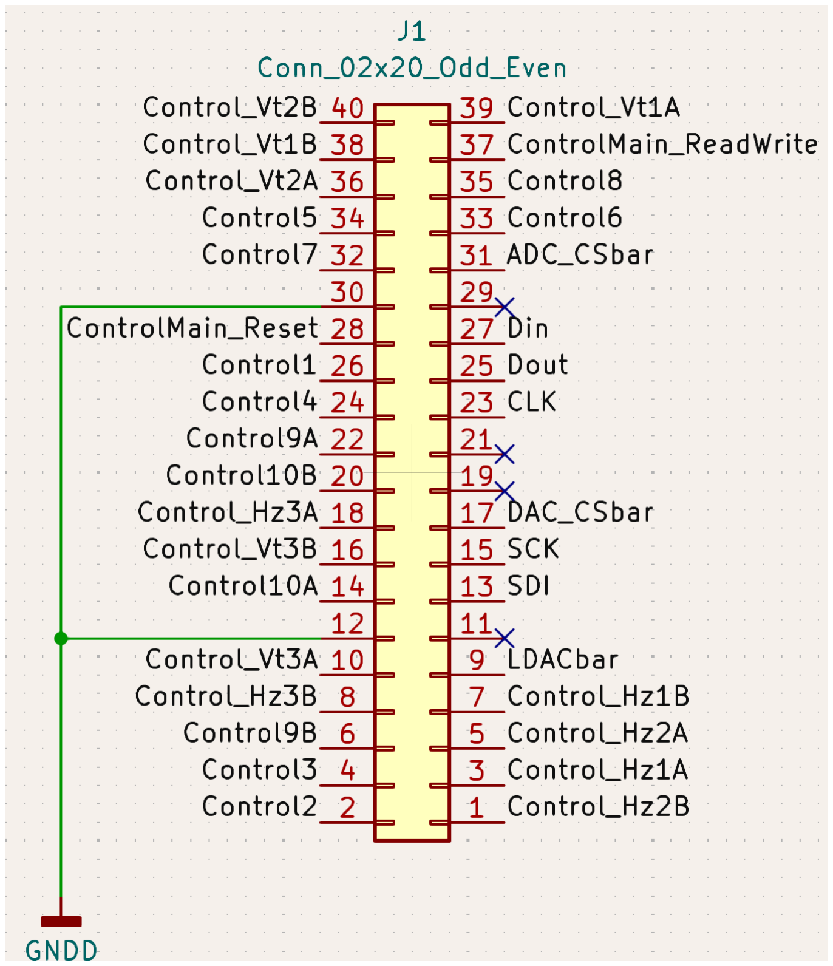
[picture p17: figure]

Note: The pins 11,12,29,30 are power and ground pins and so cannot be programmed. This is ensured in the mapping.

Due to the lack of time, PCB Lab didn’t print our silkscreen. To identify the pin 1 in the FPGA header, look at the main PCB such that the RRAM connection header and the power header are towards your side with the FPGA header towards the right. In this orientation, the above image exactly matches the FPGA headers. So the bottom right pin will be pin 1.

While holding the PCB in the same orientation, the RRAM connection header and power header are as follows:

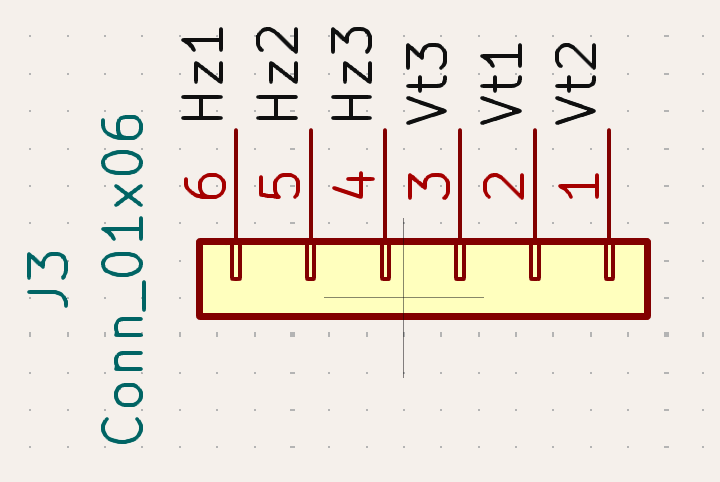
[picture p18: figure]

Note: The Vt and Hz pins are not in a serial order because of ease in routing. Do ensure this pinout when connecting.

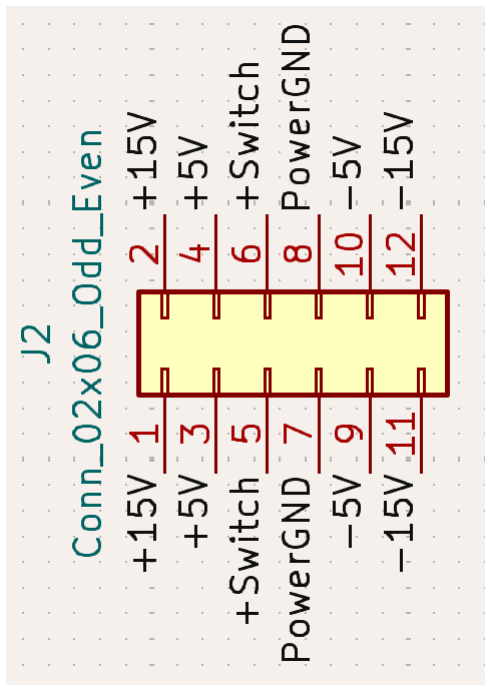
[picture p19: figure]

Note: Here the upper and lower header are exactly the same, just for backup.

The +15V and -15V connect to the OpAmps, the +5V and GND connect to the DAC and ADC, and the +Switch and -5V connect to the Switches.
Currently for testing, we connected +15V, +5V, +Switch to +5V; GND, -5V to GND and -15V to –5V. For reliable switching, as per the datasheet, the following two combinations work:
| +Switch | -5V
1 | +5V | GND
2 | +9V | –5V

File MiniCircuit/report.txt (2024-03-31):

Plotted to 'C:\Users\harsh\Desktop\IIT Bombay\Semester 6\EE 344\Main Work\EDL2024\MiniCircuit\MiniCircuit-F_Cu.gbr'.
Plotted to 'C:\Users\harsh\Desktop\IIT Bombay\Semester 6\EE 344\Main Work\EDL2024\MiniCircuit\MiniCircuit-B_Cu.gbr'.
Plotted to 'C:\Users\harsh\Desktop\IIT Bombay\Semester 6\EE 344\Main Work\EDL2024\MiniCircuit\MiniCircuit-Edge_Cuts.gbr'.
Created Gerber job file 'C:\Users\harsh\Desktop\IIT Bombay\Semester 6\EE 344\Main Work\EDL2024\MiniCircuit\MiniCircuit-job.gbrjob'.
Info: Done.

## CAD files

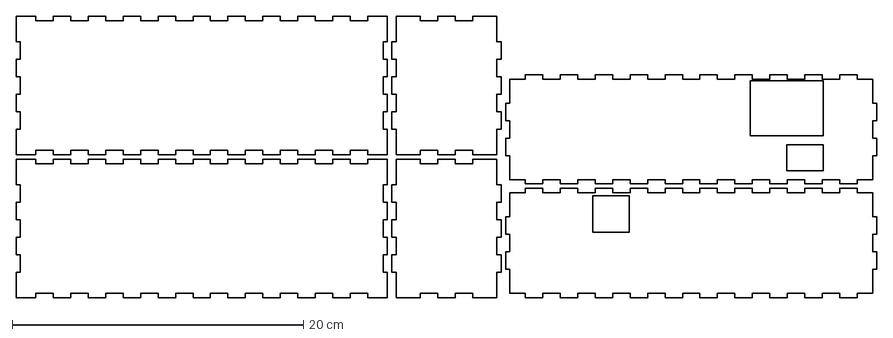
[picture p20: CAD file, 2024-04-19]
Enclosure_Fusion360.dxf
59.1 x 19.3 cm

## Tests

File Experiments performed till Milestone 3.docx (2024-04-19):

Testing:

Analog

A. Simplified Circuit
B. Final Circuit

Digital

A. Elementary and advanced ADC, DAC
B. FPGA and laptop communication

PCB

A. Simplified Circuit: in process of soldering and testing
B. Final Circuit: sent for fab

A. Simplified Circuit:

We designed a simplified circuit along with elementary DAC and ADC on 2 x 2 resistive crossbar array for the proof of concept of the flow and tested it .
The testing was complete with sending a pulse of 100us from DAC and sampling the value at the correct instance of the pulse, measured by the ADC and displayed on the onboard LEDs of FPGA board.

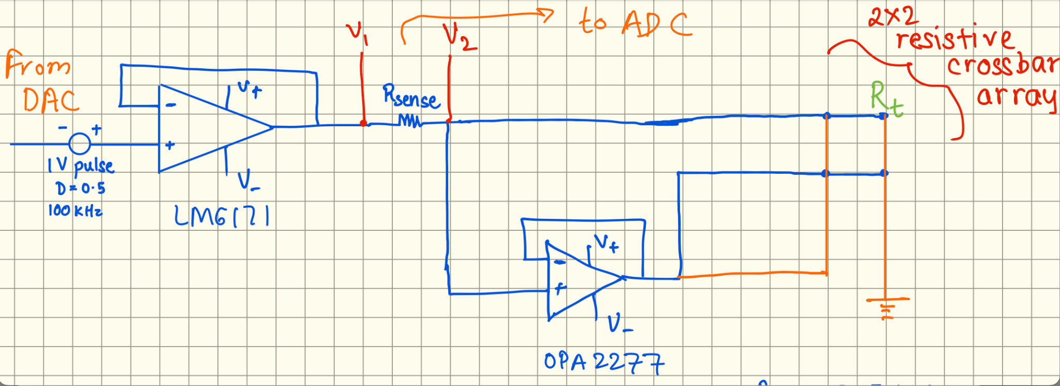
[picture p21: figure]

This is the basic setup of the circuit that we tested for various frequencies and got correct resistance measurements with no sneak currents observed.

We got very good results for a square pulse of width 100 us.

We added a buffer amplifier before ADC in the PCB schematic for this simplified circuit along with all the switching circuitry and another amplifier for write operation.

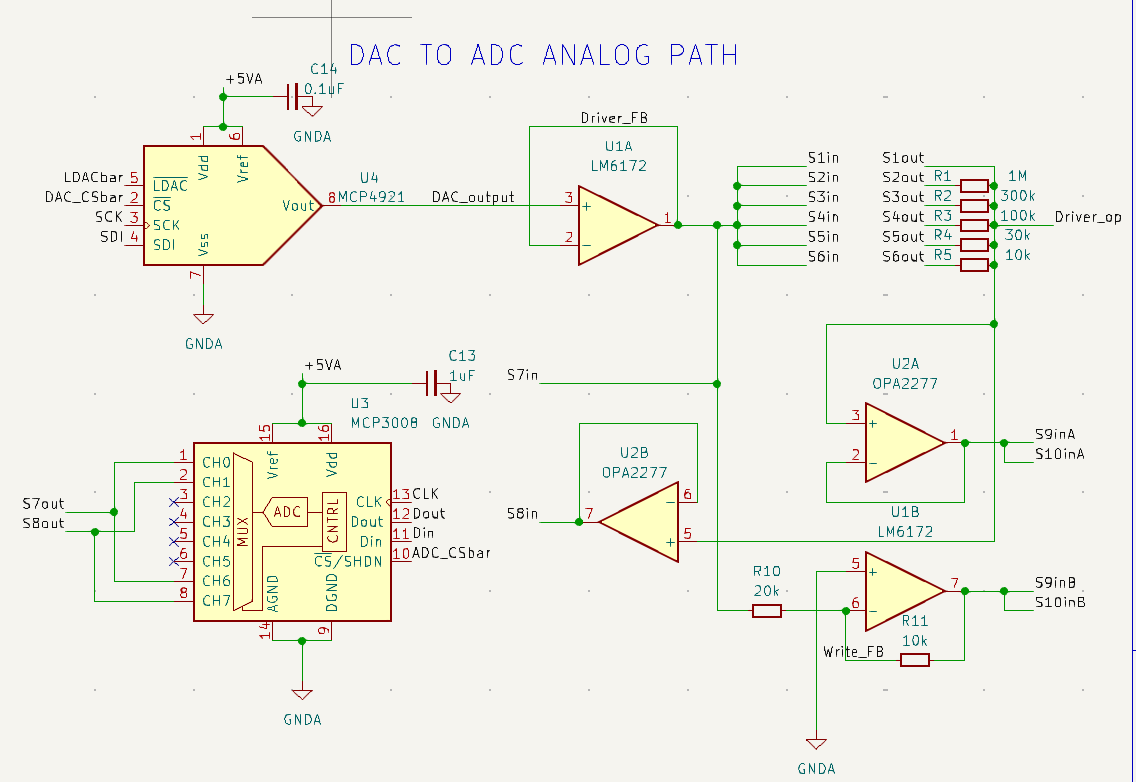
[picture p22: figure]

We received this PCB on Monday at the end of the lab session.

Ideal circuit flow:

Schematic by hand: Schematic_hand.pdf (https://drive.google.com/file/d/19IjKuICe31It-q4dtc5-FK4axgM6YBKp/view?usp=share_link)

Ideal op amps:

We completed the entire schematic by hand for the ideal circuit that we wanted to get working.

We tested each amplifier of the ideal circuit individually at different frequencies and gains. We got the current feedback amplifiers working, however, we had to cancel this plan almost entirely due to an issue in DAC we observed while testing.

Advanced DAC

Issue in DAC: We got the DAC soldered, and while testing it, we observed that two pins were shorted. We desoldered it, but realized that the two pins were shorted internally. We tried writing VHDL drivers and connecting current feedback amps but it was not responding. Maheshwar sir said that one possible issue could be that the DAC got damaged while soldering because it was ESD sensitive.

Advanced ADC

We were able to get the VHDL drivers for ADC working, even though we had very less time left for final PCB submission by then. The differential ADC responded initially, however, the ADC got damaged during testing for a reason we could not pin point.

We had a spare ADC and could have tried on it again along with amplifiers, however, we had very less time remaining until the final PCB deadline and needed to finalize the design. Hence, we decided to stick with the simplified design version along with a few additional capabilities for our final design.

FPGA and Laptop communication:

We are successfully able to send data from fpga to laptop and also send from laptop to fpga. This has been demonstrated in the videos of Milestone 3.

On the laptop, a simple python program that uses a library(needs quartus installed on the device) handles the communication, this is being integrated with a GUI.

Another challenge faced in programming was:

The jtag UART client on the FPGA which communicates with the Intel Avalon interface was written in verilog and drivers for ADC DAC in VHDL. A testing code was generated to perform mixed synthesis of verilog and vhdl files, and dumped onto the De0 Nano board, which worked successfully.

B. Final circuit flow:
We added support for a -5V pulse to be sent. Moreover, we increased the size of the crossbar array to 3 x 3.

In the PCB, we rectified a mistake in the “write” buffer amplifier setup.

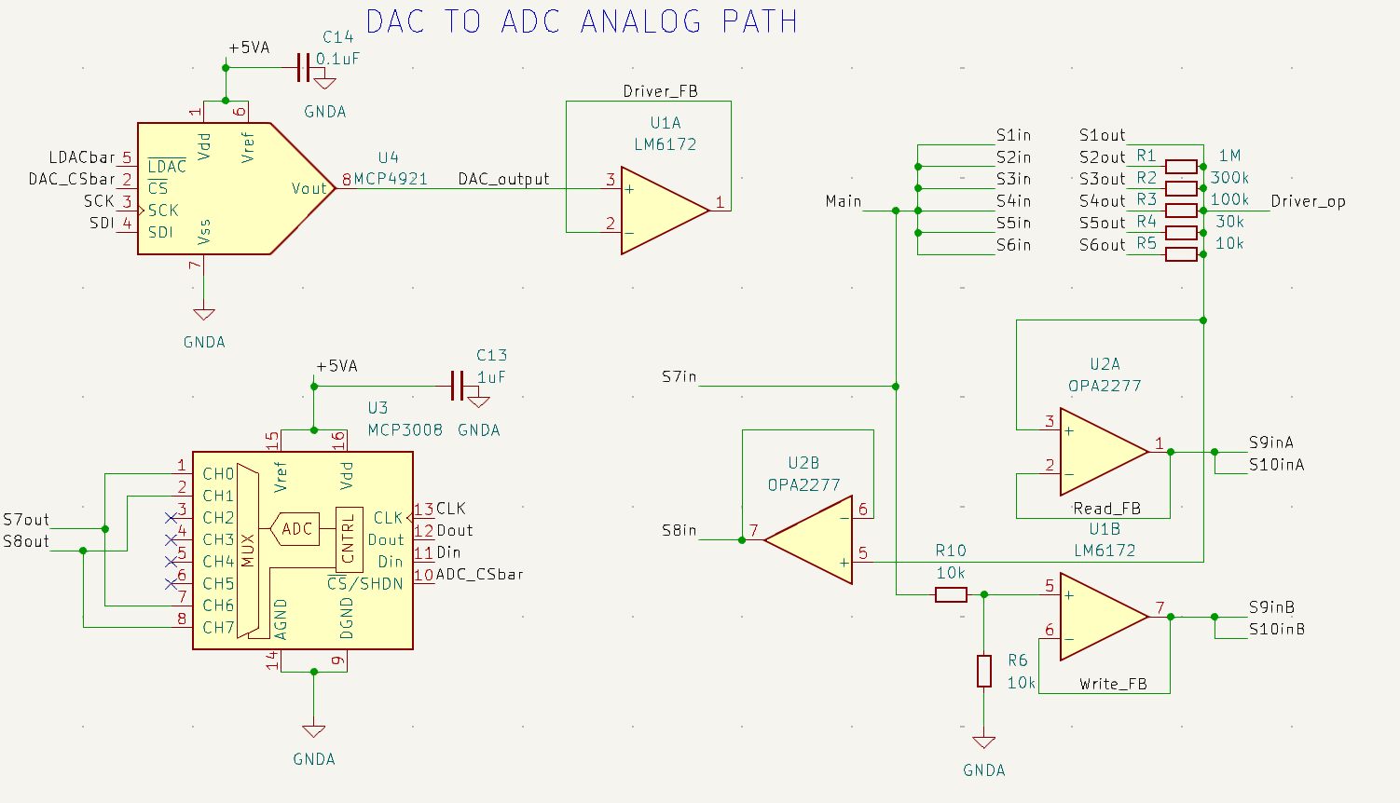
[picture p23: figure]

Testing of switches:

We want the switches to allow voltages from -5V to +5V. We didn’t have dual supply switches, but we managed to find CD4066 which takes positive supply of upto 20V with respect Vss(negative supply voltage). When working in 10V mode(that is desired since we need to run from -5V to +5V), the voltage at the control line needs to be less than +2V with respect to Vss for the switch to be open, that is, -3V with respect to circuit ground. But FPGA cannot provide -3V, hence, we tested the switch in 14V mode. Here, the switch is open at 0V and closed at 3.3V, as desired. We also tested its voltage rise time when the switch closes and it is of the order of nanoseconds, so that is not an issue. Hence, we will be supplying -5V and +9V to the switch.

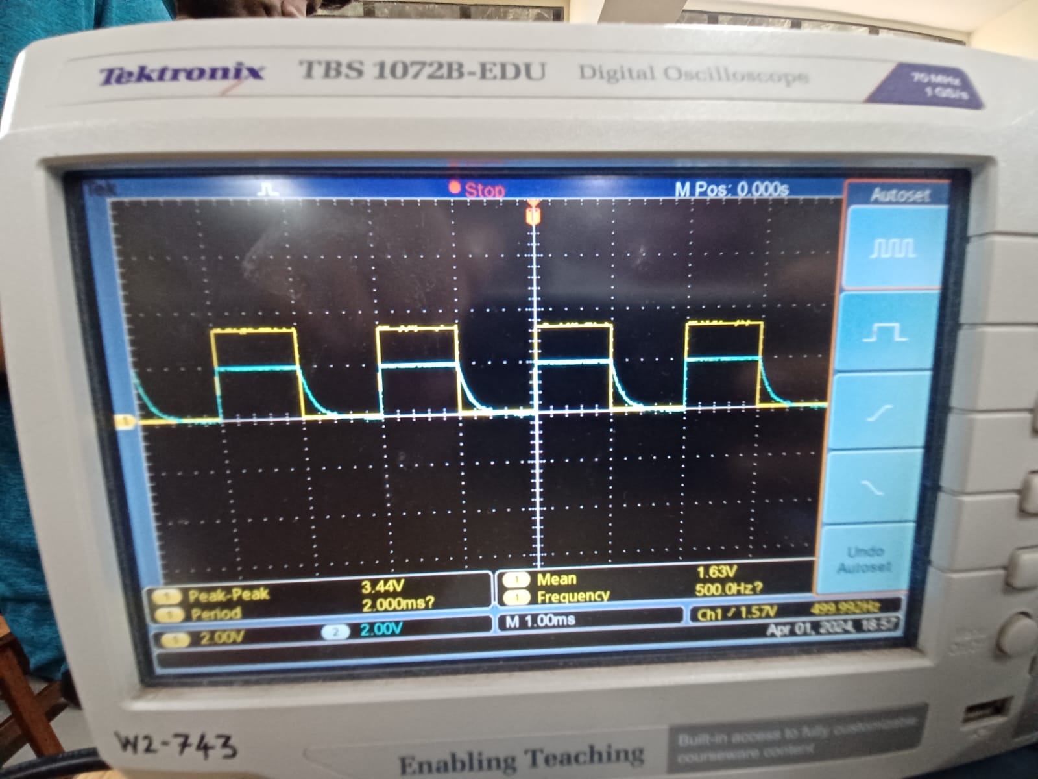
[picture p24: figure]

Power Supply:

We have completed the schematic, testing and PCB design of the power circuit. All the components and the design works fine.

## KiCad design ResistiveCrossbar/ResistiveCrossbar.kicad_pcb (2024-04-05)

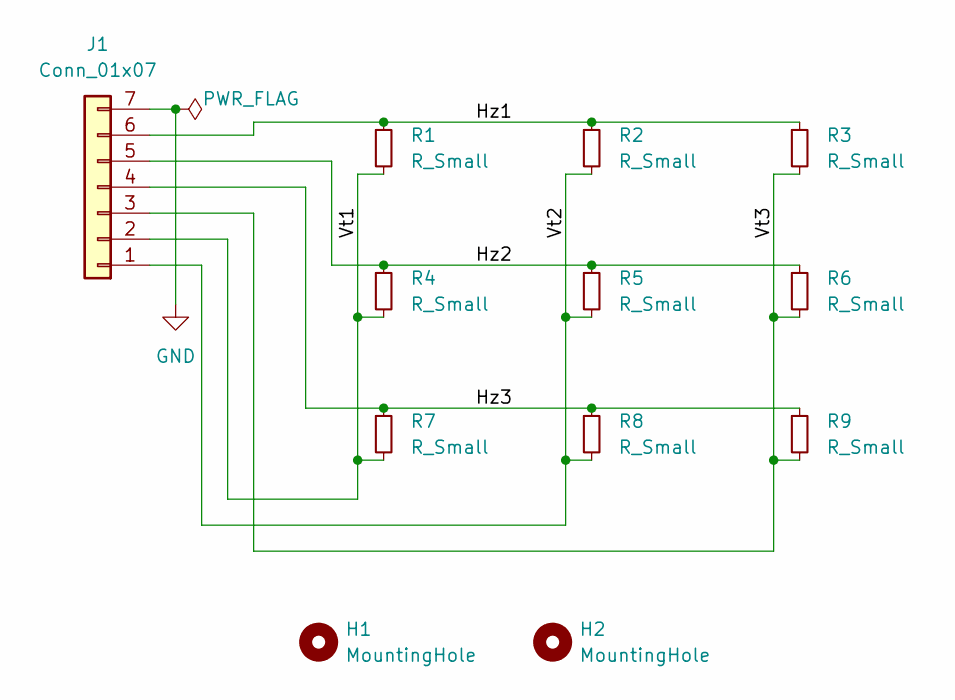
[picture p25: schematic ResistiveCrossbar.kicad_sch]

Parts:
H1, H2: MountingHole; MountingHole_3mm
J1: Conn_01x07; PinHeader_1x07_P2.54mm_Vertical
R1, R2, R3, R4, R5, R6, R7, R8, R9: R_Small; R_1206_3216Metric_Pad1.30x1.75mm_HandSolder

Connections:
/Hz1: J1.6, R1.1, R2.1, R3.1
/Hz2: J1.5, R4.1, R5.1, R6.1
/Hz3: J1.4, R7.1, R8.1, R9.1
/Vt1: J1.2, R1.2, R4.2, R7.2
/Vt2: J1.1, R2.2, R5.2, R8.2
/Vt3: J1.3, R3.2, R6.2, R9.2
GND: J1.7

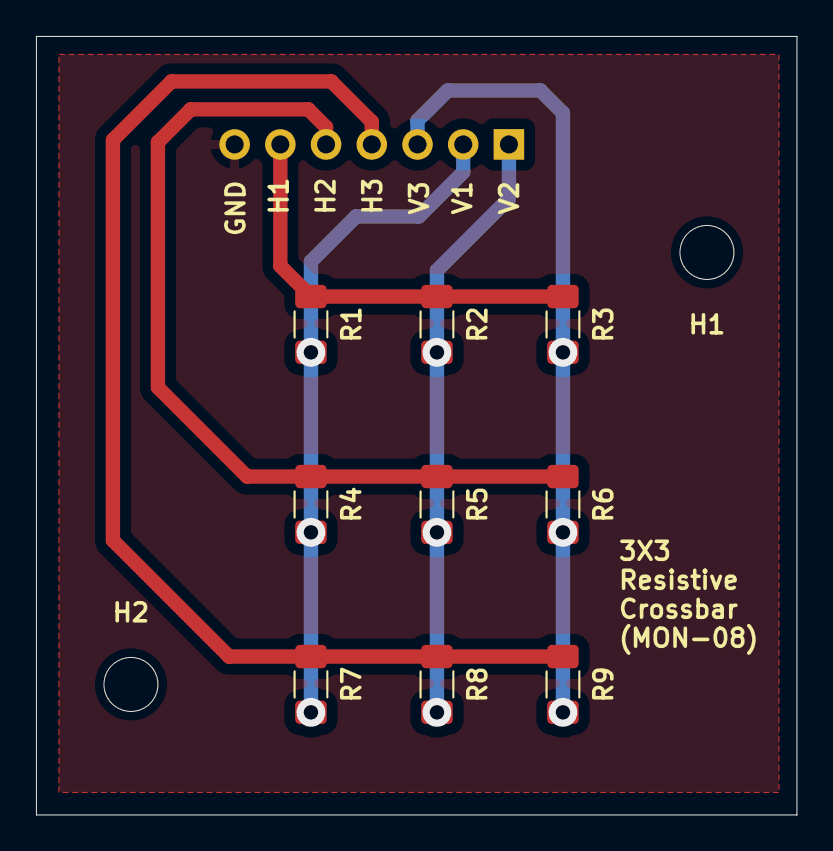
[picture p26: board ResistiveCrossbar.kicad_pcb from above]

Board: 2 copper layers, 42.2 x 43.2 mm, 12 parts (1 on the bottom side), 6 nets.

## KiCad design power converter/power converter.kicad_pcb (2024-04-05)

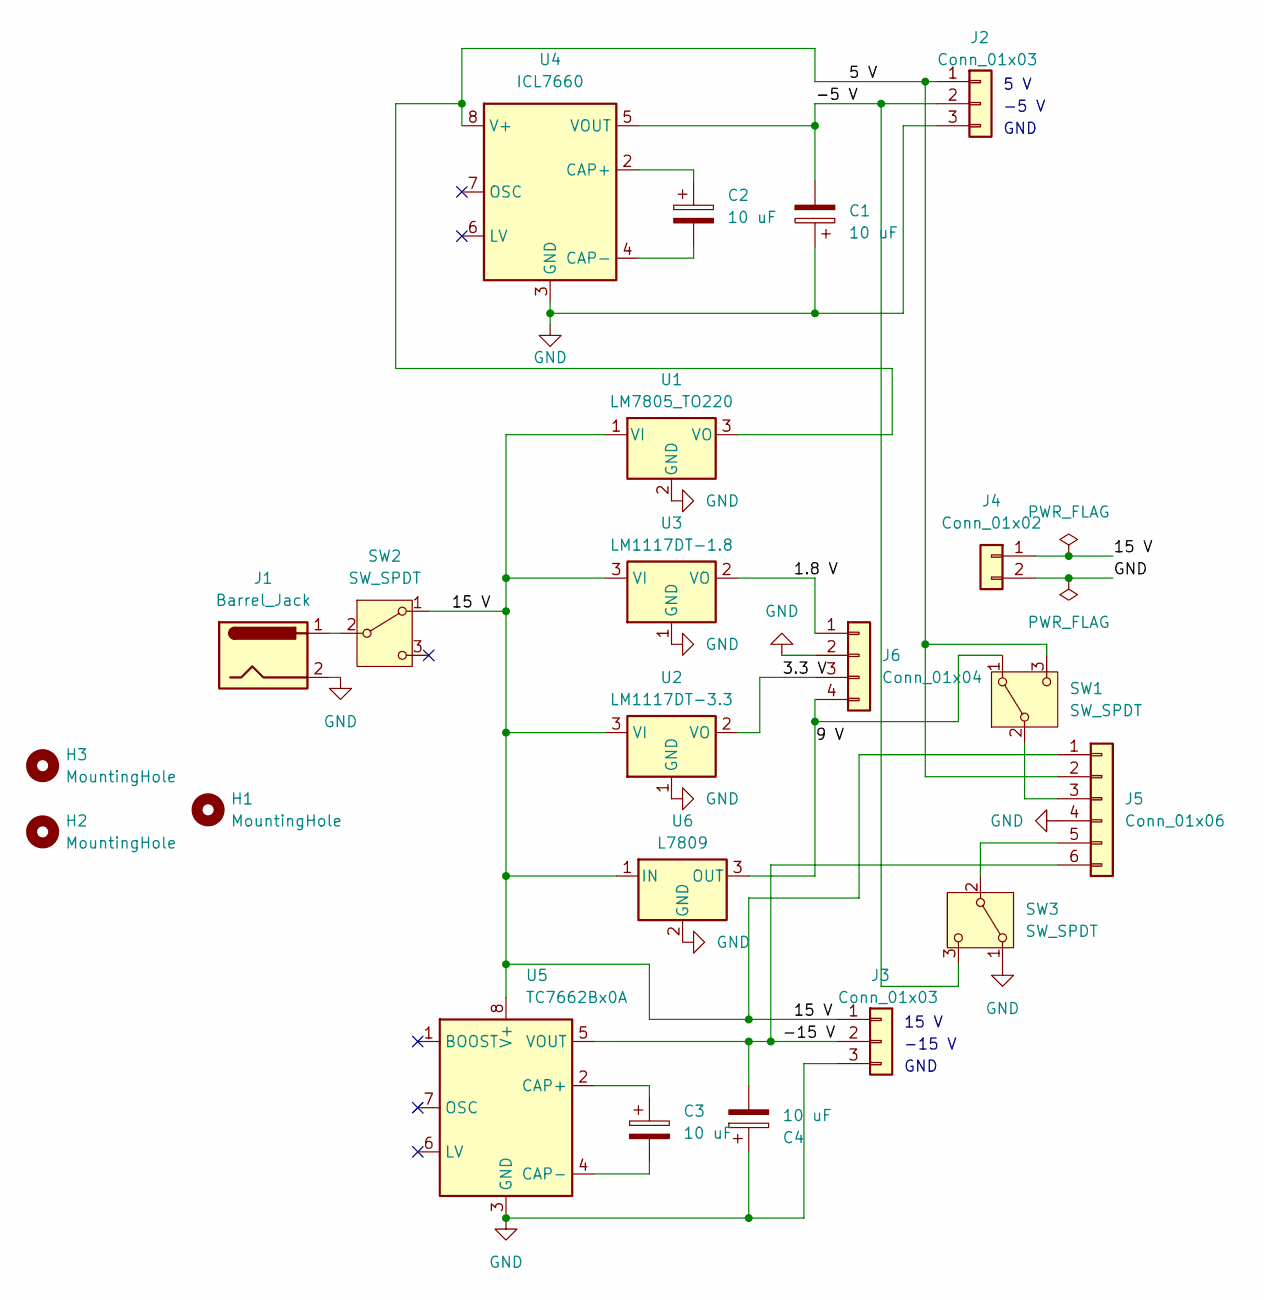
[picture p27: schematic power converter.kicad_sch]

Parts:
C1, C2, C3, C4: 10 uF; CP_Radial_D5.0mm_P2.50mm
H1, H2, H3: MountingHole; MountingHole_3mm
J1: Barrel_Jack; BarrelJack_Horizontal
J2, J3: Conn_01x03; PinHeader_1x03_P2.54mm_Vertical
J4: Conn_01x02; PinHeader_1x02_P2.54mm_Vertical
J5: Conn_01x06; PinSocket_1x06_P2.54mm_Vertical
J6: Conn_01x04; PinSocket_1x04_P2.54mm_Vertical
SW1, SW2, SW3: SW_SPDT; Slide_switch
U1: LM7805_TO220; TO-220-3_Vertical
U2: LM1117DT-3.3; TO-252-3_TabPin2
U3: LM1117DT-1.8; TO-252-3_TabPin2
U4: ICL7660; SOIC-8_3.9x4.9mm_P1.27mm
U5: TC7662Bx0A; SOIC-8_3.9x4.9mm_P1.27mm
U6: L7809; TO-220-3_Vertical

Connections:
/1.8 V: J6.1, U3.2 (VO)
/3.3 V: J6.3, U2.2 (VO)
/5 V: J2.1, J5.2, SW1.3 (C), U1.3 (VO), U4.8 (V+)
/9 V: J6.4, SW1.1 (A), U6.3 (OUT)
/15 V: J3.1, J4.1, J5.1, SW2.1 (A), U1.1 (VI), U2.3 (VI), U3.3 (VI), U5.8 (V+), U6.1 (IN)
/-5 V: C1.2, J2.2, SW3.3 (C), U4.5 (VOUT)
/-15 V: C4.2, J3.2, J5.6, U5.5 (VOUT)
GND: C1.1, C4.1, J1.2, J2.3, J3.3, J4.2, J5.4, J6.2, SW3.1 (A), U1.2 (GND), U2.1 (GND), U3.1 (GND), U4.3 (GND), U5.3 (GND), U6.2 (GND)
unnamed: J5.3, SW1.2 (B)
unnamed: J5.5, SW3.2 (B)
unnamed: J1.1, SW2.2 (B)
unnamed: C2.1, U4.2 (CAP+)
unnamed: C2.2, U4.4 (CAP-)
unnamed: C3.1, U5.2 (CAP+)
unnamed: C3.2, U5.4 (CAP-)

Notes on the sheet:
5 V
-15 V
GND
-5 V
15 V

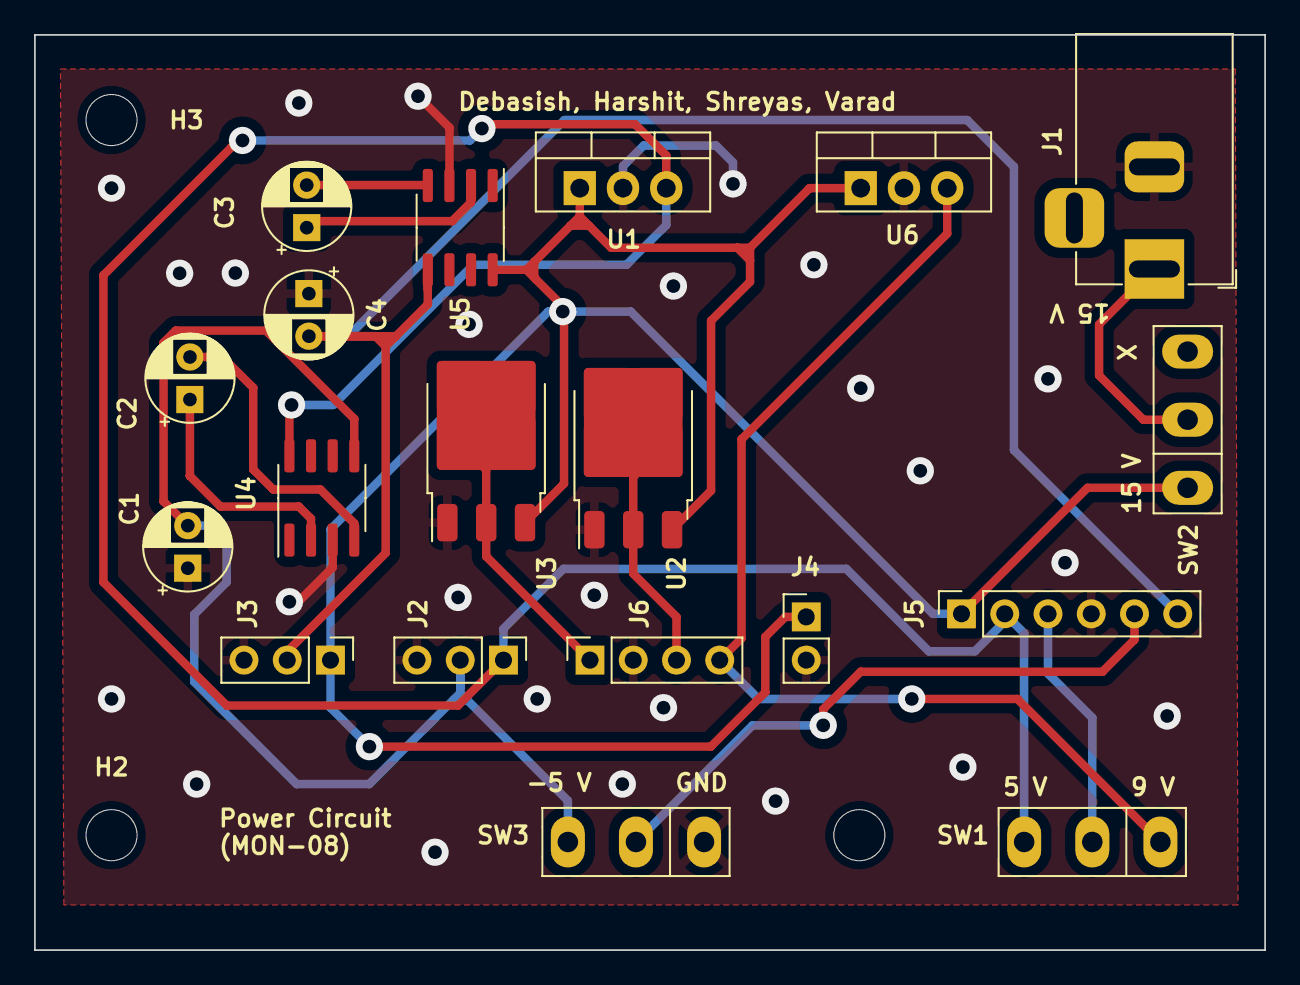
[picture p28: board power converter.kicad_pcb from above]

Board: 2 copper layers, 72.2 x 53.8 mm, 22 parts (0 on the bottom side), 15 nets.

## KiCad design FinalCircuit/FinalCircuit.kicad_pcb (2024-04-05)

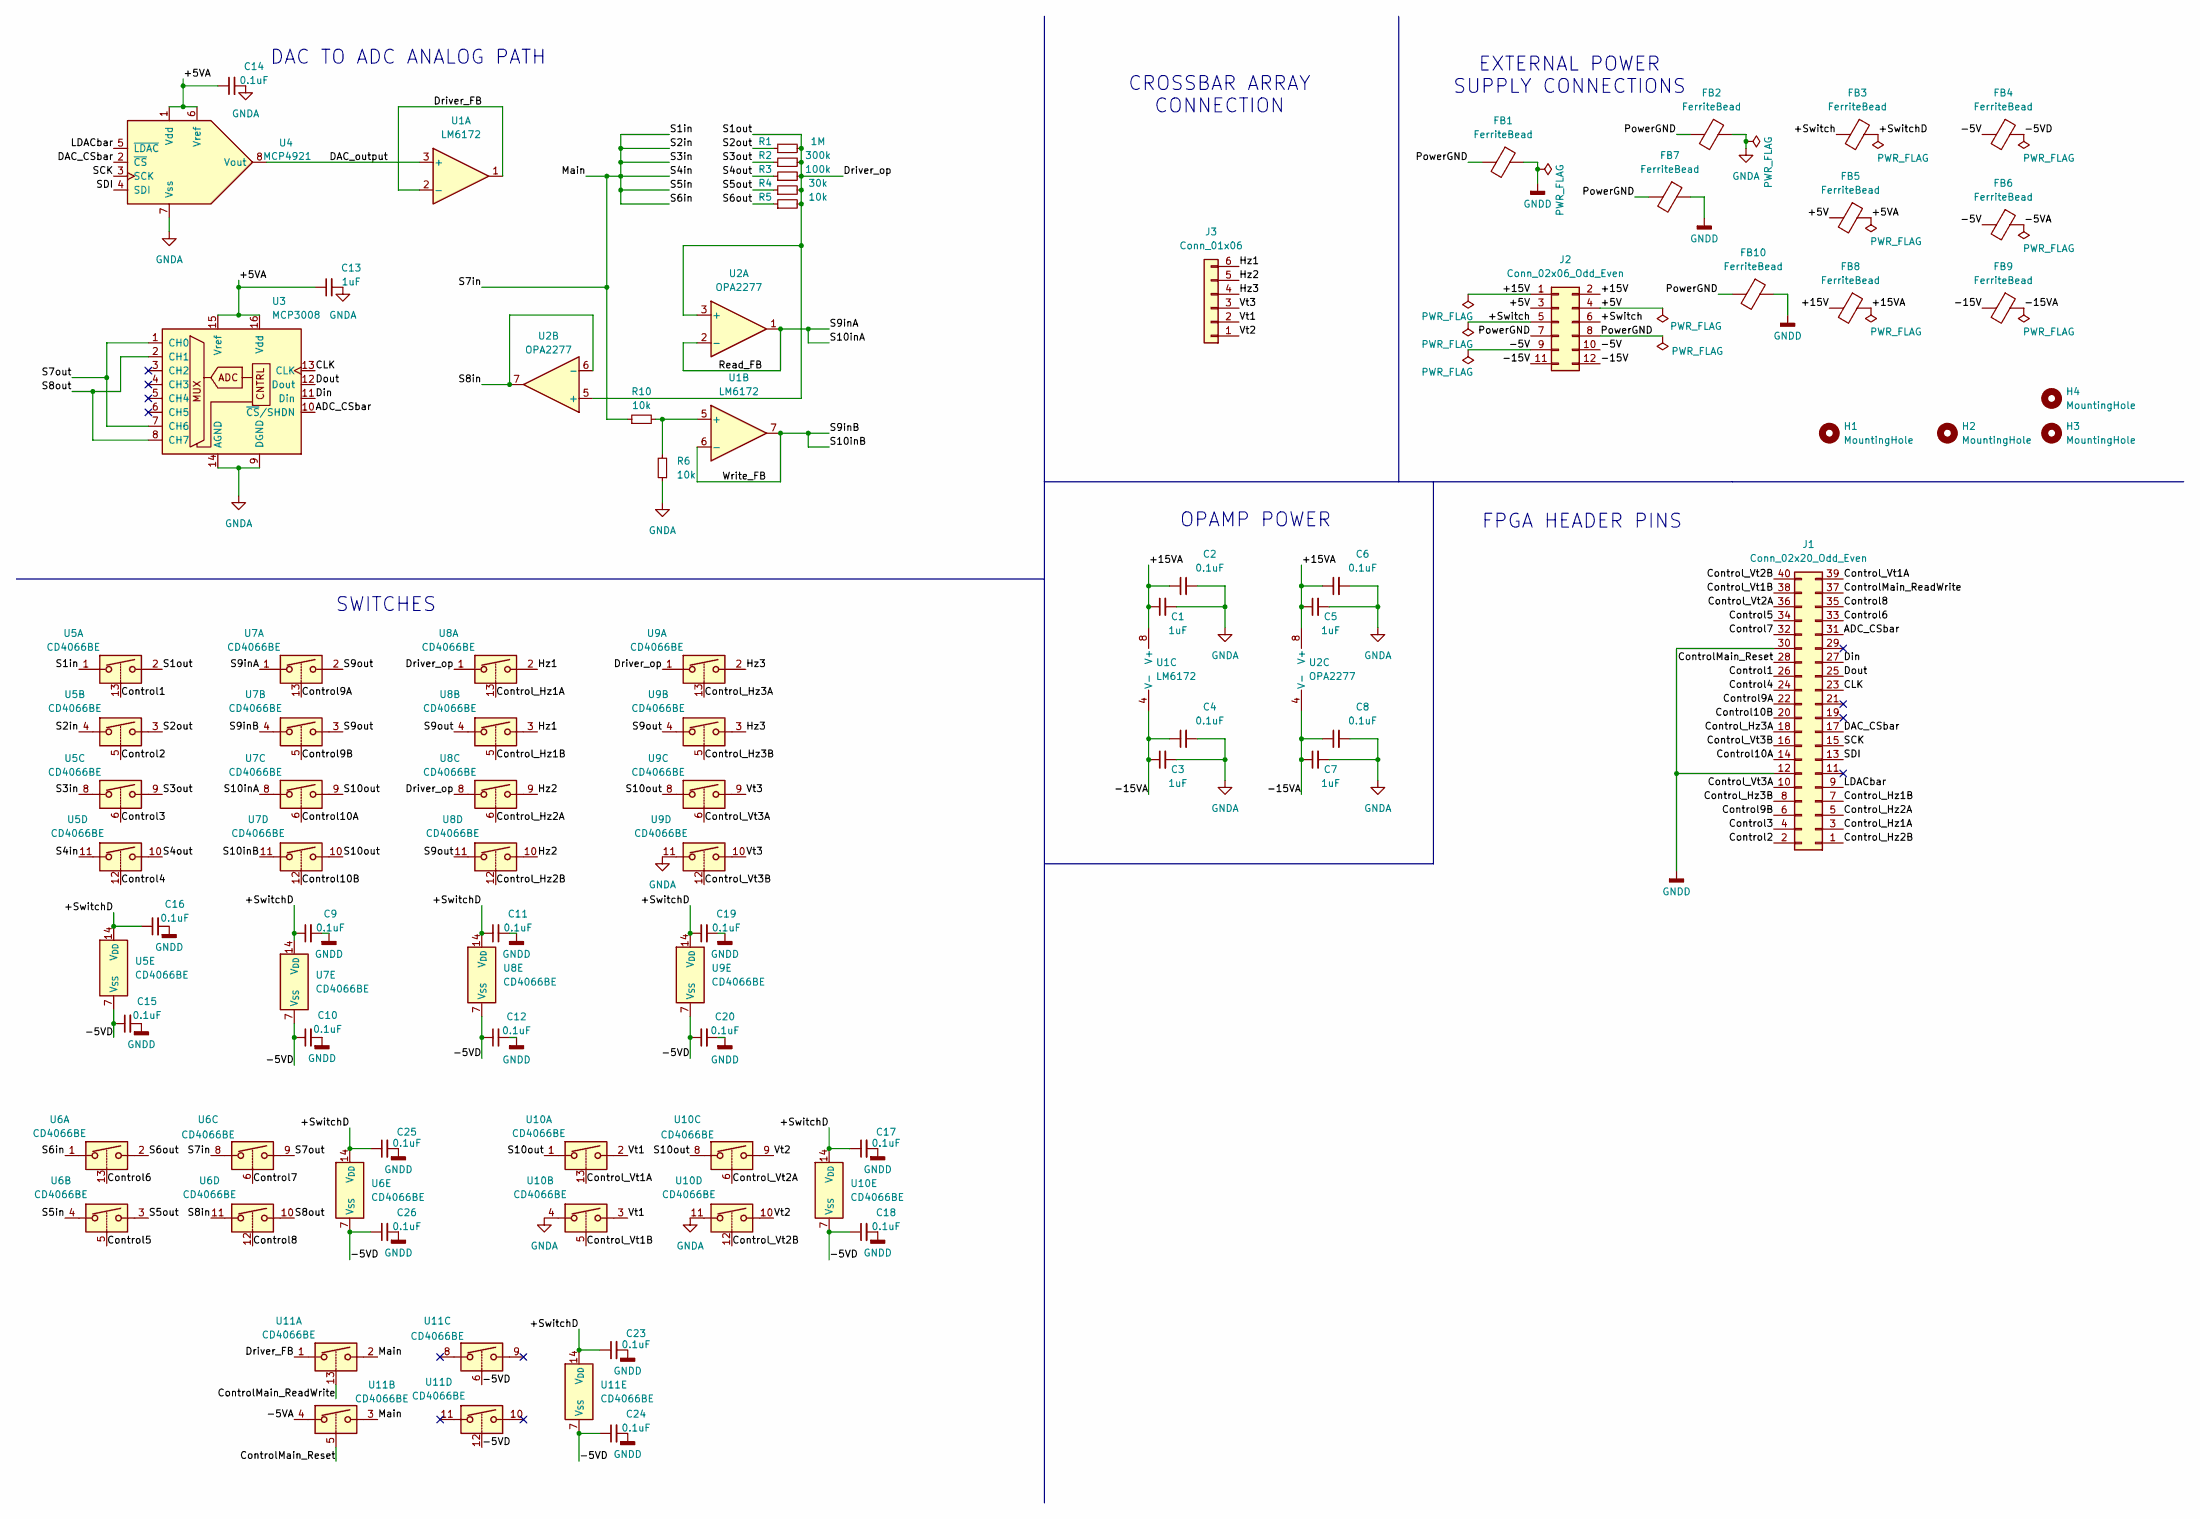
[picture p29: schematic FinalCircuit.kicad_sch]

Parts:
C1, C3, C5, C7, C13: 1uF; C_1206_3216Metric_Pad1.33x1.80mm_HandSolder
C2, C4, C6, C8, C9, C10, C11, C12, C14, C15, C16, C17, C18, C19, C20, C23, C24, C25, C26: 0.1uF; C_1206_3216Metric_Pad1.33x1.80mm_HandSolder
FB1, FB2, FB3, FB4, FB5, FB6, FB7, FB8, FB9, FB10: FerriteBead; L_0805_2012Metric_Pad1.15x1.40mm_HandSolder
H1, H2, H3, H4: MountingHole; MountingHole_3mm
J1: Conn_02x20_Odd_Even; PinSocket_2x20_P2.54mm_Vertical
J2: Conn_02x06_Odd_Even; PinHeader_2x06_P2.54mm_Vertical
J3: Conn_01x06; PinSocket_1x06_P2.54mm_Vertical
R1: 1M; R_1206_3216Metric_Pad1.30x1.75mm_HandSolder
R2: 300k; R_1206_3216Metric_Pad1.30x1.75mm_HandSolder
R3: 100k; R_1206_3216Metric_Pad1.30x1.75mm_HandSolder
R4: 30k; R_1206_3216Metric_Pad1.30x1.75mm_HandSolder
R5, R6, R10: 10k; R_1206_3216Metric_Pad1.30x1.75mm_HandSolder
U1: LM6172; DIP-8_W7.62mm_Socket
U2: OPA2277; DIP-8_W7.62mm_Socket
U3: MCP3008; DIP-16_W7.62mm_Socket
U4: MCP4921; DIP-8_W7.62mm_Socket
U5, U6, U7, U8, U9, U10, U11: CD4066BE; DIP-14_W7.62mm_Socket

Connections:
/+5V: FB5.2, J2.3, J2.4
/+5VA: C13.1, C14.1, FB5.1, U3.15 (Vref), U3.16 (Vdd), U4.1 (Vdd), U4.6 (Vref)
/+15V: FB8.2, J2.1, J2.2
/+15VA: C1.1, C2.1, C5.1, C6.1, FB8.1, U1.8 (V+), U2.8 (V+)
/+Switch: FB3.2, J2.5, J2.6
/+SwitchD: C9.1, C11.1, C16.1, C17.1, C19.1, C23.1, C25.1, FB3.1, U5.14 (V_{DD}), U6.14 (V_{DD}), U7.14 (V_{DD}), U8.14 (V_{DD}), U9.14 (V_{DD}), U10.14 (V_{DD}), U11.14 (V_{DD})
/-5V: FB4.2, FB6.2, J2.9, J2.10
/-5VA: FB6.1, U11.4
/-5VD: C10.1, C12.1, C15.1, C18.1, C20.1, C24.1, C26.1, FB4.1, U5.7 (V_{SS}), U6.7 (V_{SS}), U7.7 (V_{SS}), U8.7 (V_{SS}), U9.7 (V_{SS}), U10.7 (V_{SS}), U11.6, U11.7 (V_{SS}), U11.12
/-15V: FB9.2, J2.11, J2.12
/-15VA: C3.1, C4.1, C7.1, C8.1, FB9.1, U1.4 (V-), U2.4 (V-)
/ADC_CSbar: J1.31, U3.10 (~CS/SHDN)
/CLK: J1.23, U3.13 (CLK)
/Control1: J1.26, U5.13
/Control2: J1.2, U5.5
/Control3: J1.4, U5.6
/Control4: J1.24, U5.12
/Control5: J1.34, U6.5
/Control6: J1.33, U6.13
/Control7: J1.32, U6.6
/Control8: J1.35, U6.12
/Control9A: J1.22, U7.13
/Control9B: J1.6, U7.5
/Control10A: J1.14, U7.6
/Control10B: J1.20, U7.12
/ControlMain_ReadWrite: J1.37, U11.13
/ControlMain_Reset: J1.28, U11.5
/Control_Hz1A: J1.3, U8.13
/Control_Hz1B: J1.7, U8.5
/Control_Hz2A: J1.5, U8.6
/Control_Hz2B: J1.1, U8.12
/Control_Hz3A: J1.18, U9.13
/Control_Hz3B: J1.8, U9.5
/Control_Vt1A: J1.39, U10.13
/Control_Vt1B: J1.38, U10.5
/Control_Vt2A: J1.36, U10.6
/Control_Vt2B: J1.40, U10.12
/Control_Vt3A: J1.10, U9.6
/Control_Vt3B: J1.16, U9.12
/DAC_CSbar: J1.17, U4.2 (~CS)
/DAC_output: U1.3 (+), U4.8 (Vout)
/Din: J1.27, U3.11 (Din)
/Dout: J1.25, U3.12 (Dout)
/Driver_FB: U1.1, U1.2 (-), U11.1
/Driver_op: R1.2, R2.2, R3.2, R4.2, R5.2, U2.3 (+), U2.5 (+), U5.2, U8.1, U8.8, U9.1
/Hz1: J3.6, U8.2, U8.3
/Hz2: J3.5, U8.9, U8.10
/Hz3: J3.4, U9.2, U9.3
/LDACbar: J1.9, U4.5 (~LDAC)
/Main: R10.1, U5.1, U5.4, U5.8, U5.11, U6.1, U6.4, U6.8, U11.2, U11.3
/PowerGND: FB1.2, FB2.2, FB7.2, FB10.2, J2.7, J2.8
/Read_FB: U2.1, U2.2 (-), U7.1, U7.8
/S2out: R1.1, U5.3
/S3out: R2.1, U5.9
/S4out: R3.1, U5.10
/S5out: R4.1, U6.3
/S6out: R5.1, U6.2
/S7out: U3.1 (CH0), U3.7 (CH6), U6.9
/S8in: U2.6 (-), U2.7, U6.11
/S8out: U3.2 (CH1), U3.8 (CH7), U6.10
/S9out: U7.2, U7.3, U8.4, U8.11, U9.4
/S10inB: U1.6 (-), U1.7, U7.4, U7.11
/S10out: U7.9, U7.10, U9.8, U10.1, U10.8
/SCK: J1.15, U4.3 (SCK)
/SDI: J1.13, U4.4 (SDI)
/Vt1: J3.2, U10.2, U10.3
/Vt2: J3.1, U10.9, U10.10
/Vt3: J3.3, U9.9, U9.10
GNDA: C1.2, C2.2, C3.2, C4.2, C5.2, C6.2, C7.2, C8.2, C13.2, C14.2, FB2.1, R6.1, U3.9 (DGND), U3.14 (AGND), U4.7 (Vss), U9.11, U10.4, U10.11
GNDD: C9.2, C10.2, C11.2, C12.2, C15.2, C16.2, C17.2, C18.2, C19.2, C20.2, C23.2, C24.2, C25.2, C26.2, FB1.1, FB7.1, FB10.1, J1.12, J1.30
unnamed: R6.2, R10.2, U1.5 (+)

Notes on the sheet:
SWITCHES
CROSSBAR ARRAY CONNECTION
DAC TO ADC ANALOG PATH
OPAMP POWER
EXTERNAL POWER SUPPLY CONNECTIONS
FPGA HEADER PINS

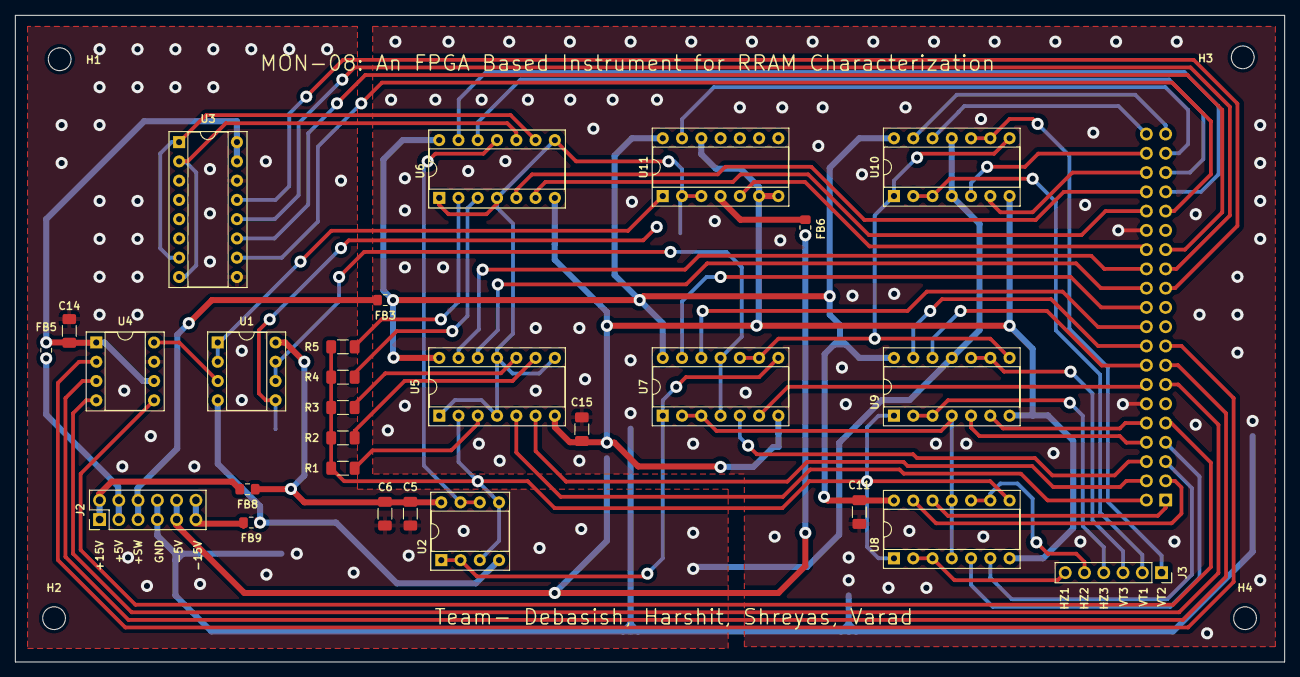
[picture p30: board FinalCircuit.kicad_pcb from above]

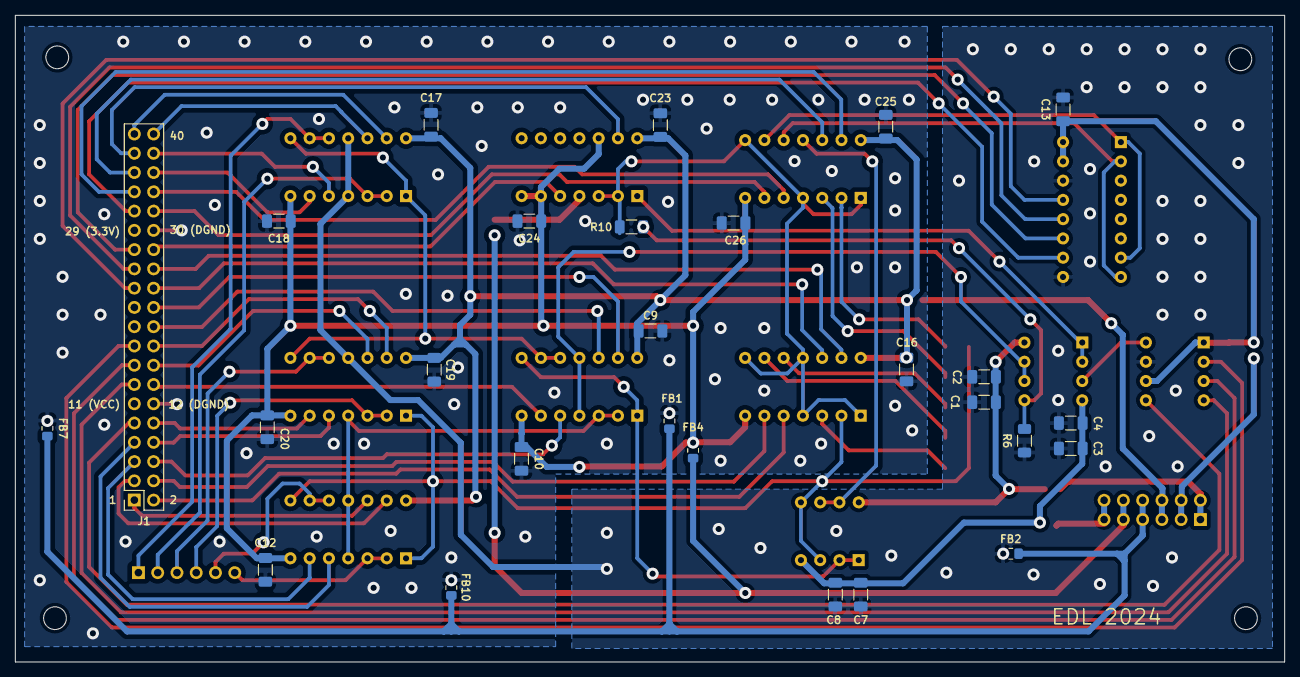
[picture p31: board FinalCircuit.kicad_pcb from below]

Board: 2 copper layers, 167.3 x 85.2 mm, 59 parts (27 on the bottom side), 71 nets.

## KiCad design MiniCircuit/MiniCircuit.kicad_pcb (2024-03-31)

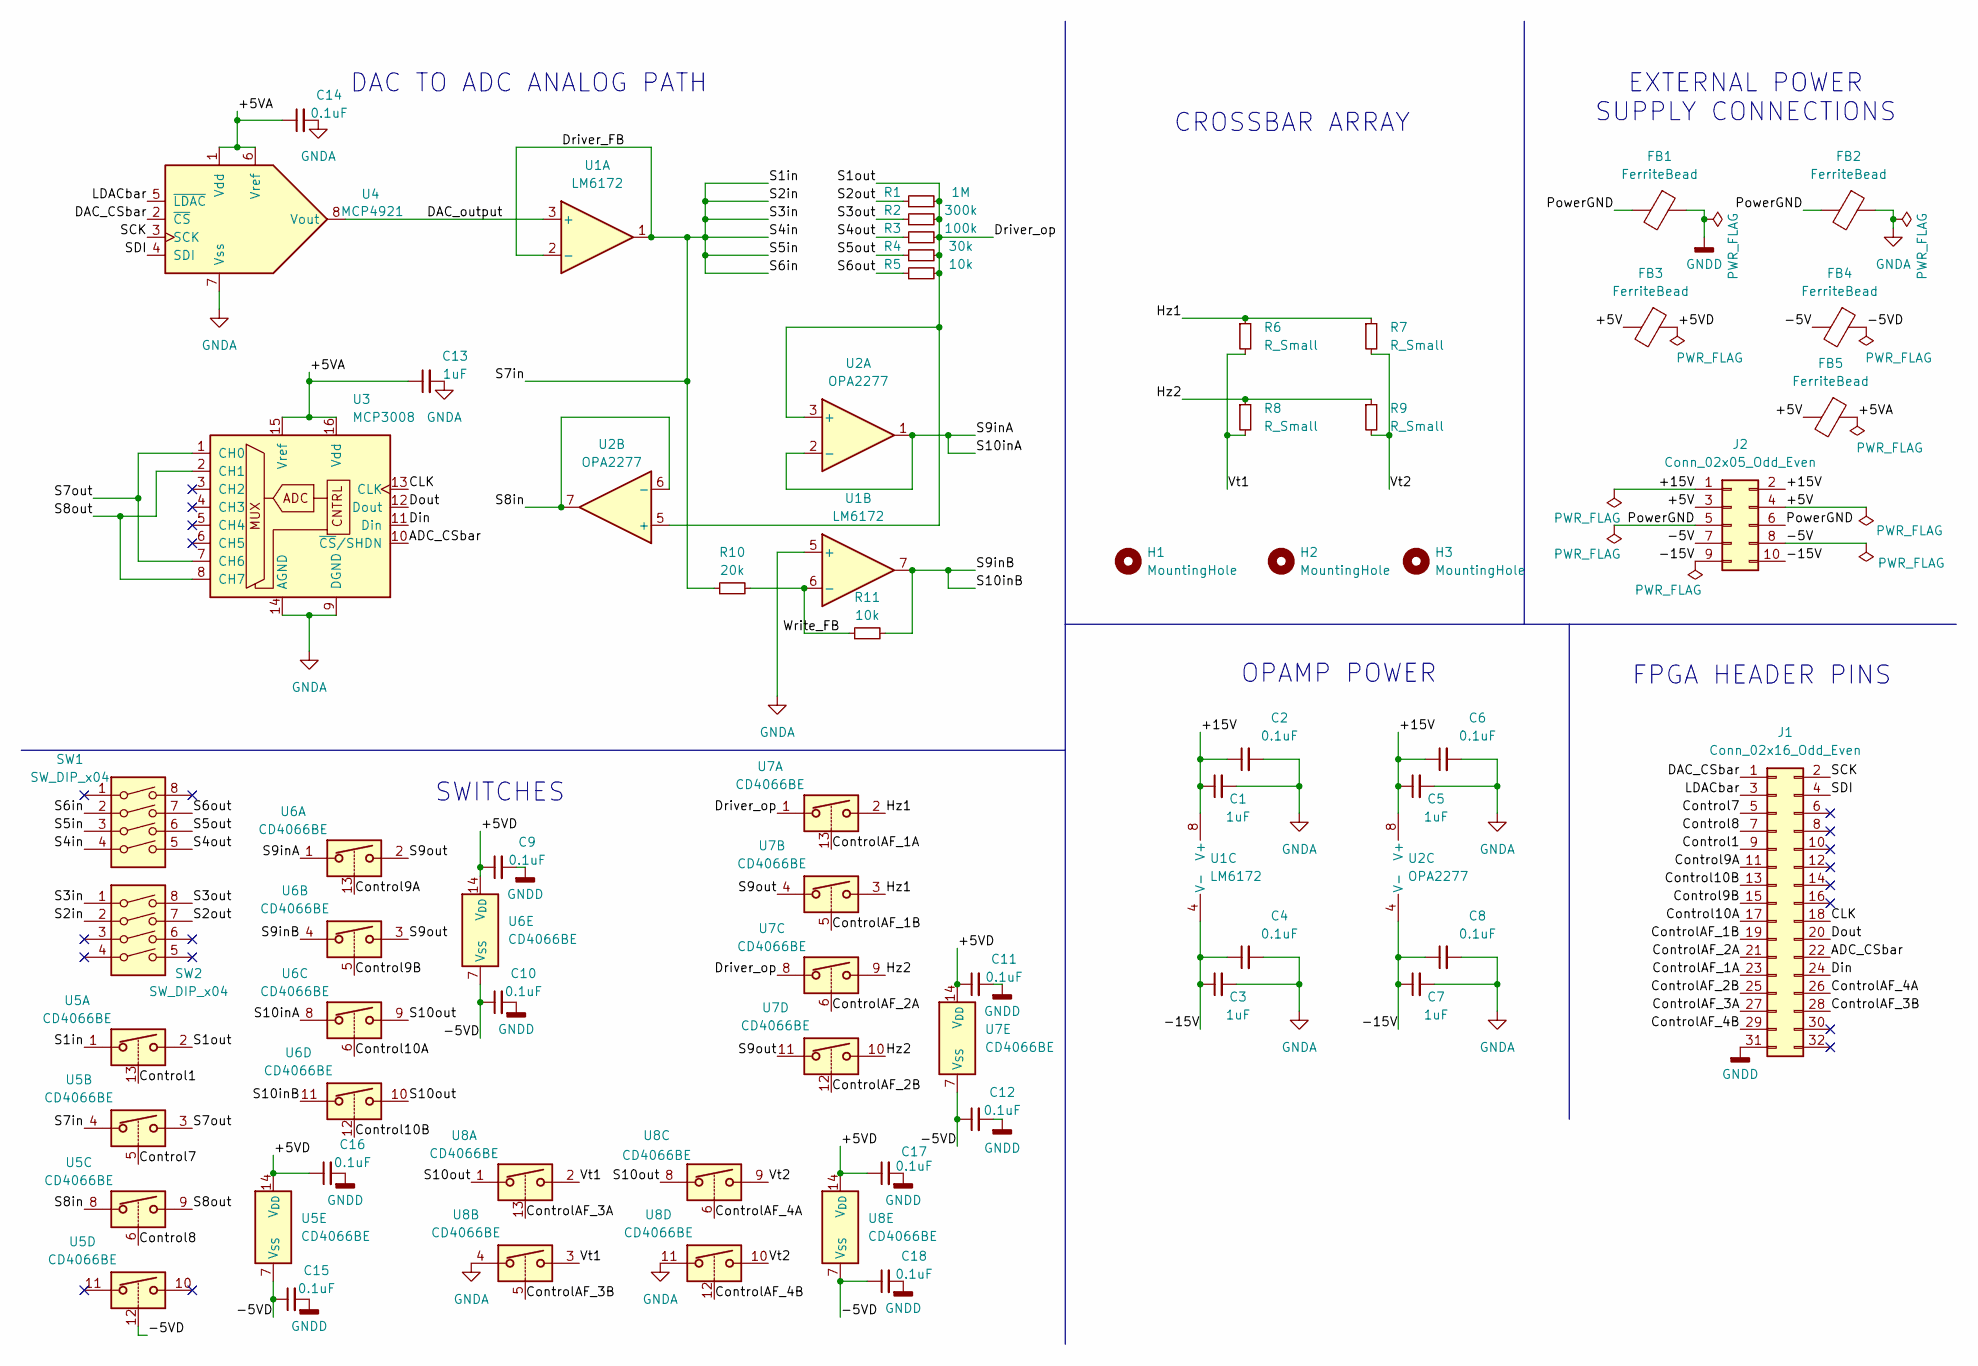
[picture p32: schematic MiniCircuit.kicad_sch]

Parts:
C1, C3, C5, C7, C13: 1uF; C_1206_3216Metric_Pad1.33x1.80mm_HandSolder
C2, C4, C6, C8, C9, C10, C11, C12, C14, C15, C16, C17, C18: 0.1uF; C_1206_3216Metric_Pad1.33x1.80mm_HandSolder
FB1, FB2, FB3, FB4, FB5: FerriteBead; L_0805_2012Metric_Pad1.15x1.40mm_HandSolder
H1, H2, H3: MountingHole; MountingHole_3mm
J1: Conn_02x16_Odd_Even; PinSocket_2x16_P2.54mm_Vertical
J2: Conn_02x05_Odd_Even; PinHeader_2x05_P2.54mm_Vertical
R1: 1M; R_1206_3216Metric_Pad1.30x1.75mm_HandSolder
R2: 300k; R_1206_3216Metric_Pad1.30x1.75mm_HandSolder
R3: 100k; R_1206_3216Metric_Pad1.30x1.75mm_HandSolder
R4: 30k; R_1206_3216Metric_Pad1.30x1.75mm_HandSolder
R5, R11: 10k; R_1206_3216Metric_Pad1.30x1.75mm_HandSolder
R6, R7, R8, R9: R_Small; R_1206_3216Metric_Pad1.30x1.75mm_HandSolder
R10: 20k; R_1206_3216Metric_Pad1.30x1.75mm_HandSolder
SW1, SW2: SW_DIP_x04; SW_DIP_SPSTx04_Slide_9.78x12.34mm_W7.62mm_P2.54mm
U1: LM6172; DIP-8_W7.62mm_Socket
U2: OPA2277; DIP-8_W7.62mm_Socket
U3: MCP3008; DIP-16_W7.62mm_Socket
U4: MCP4921; DIP-8_W7.62mm_Socket
U5, U6, U7, U8: CD4066BE; DIP-14_W7.62mm_Socket

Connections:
/+5V: FB3.2, FB5.2, J2.3, J2.4
/+5VA: C13.1, C14.1, FB5.1, U3.15 (Vref), U3.16 (Vdd), U4.1 (Vdd), U4.6 (Vref)
/+5VD: C9.1, C11.1, C16.1, C17.1, FB3.1, U5.14 (V_{DD}), U6.14 (V_{DD}), U7.14 (V_{DD}), U8.14 (V_{DD})
/+15V: C1.1, C2.1, C5.1, C6.1, J2.1, J2.2, U1.8 (V+), U2.8 (V+)
/-5V: FB4.2, J2.7, J2.8
/-5VD: C10.1, C12.1, C15.1, C18.1, FB4.1, U5.7 (V_{SS}), U5.12, U6.7 (V_{SS}), U7.7 (V_{SS}), U8.7 (V_{SS})
/-15V: C3.1, C4.1, C7.1, C8.1, J2.9, J2.10, U1.4 (V-), U2.4 (V-)
/ADC_CSbar: J1.22, U3.10 (~CS/SHDN)
/CLK: J1.18, U3.13 (CLK)
/Control1: J1.9, U5.13
/Control7: J1.5, U5.5
/Control8: J1.7, U5.6
/Control9A: J1.11, U6.13
/Control9B: J1.15, U6.5
/Control10A: J1.17, U6.6
/Control10B: J1.13, U6.12
/ControlAF_1A: J1.23, U7.13
/ControlAF_1B: J1.19, U7.5
/ControlAF_2A: J1.21, U7.6
/ControlAF_2B: J1.25, U7.12
/ControlAF_3A: J1.27, U8.13
/ControlAF_3B: J1.28, U8.5
/ControlAF_4A: J1.26, U8.6
/ControlAF_4B: J1.29, U8.12
/DAC_CSbar: J1.1, U4.2 (~CS)
/DAC_output: U1.3 (+), U4.8 (Vout)
/Din: J1.24, U3.11 (Din)
/Dout: J1.20, U3.12 (Dout)
/Driver_FB: R10.1, SW1.2, SW1.3, SW1.4, SW2.1, SW2.2, U1.1, U1.2 (-), U5.1, U5.4
/Driver_op: R1.2, R2.2, R3.2, R4.2, R5.2, U2.3 (+), U2.5 (+), U5.2, U7.1, U7.8
/Hz1: R6.1, R7.1, U7.2, U7.3
/Hz2: R8.1, R9.1, U7.9, U7.10
/LDACbar: J1.3, U4.5 (~LDAC)
/PowerGND: FB1.2, FB2.2, J2.5, J2.6
/S2out: R1.1, SW2.7
/S3out: R2.1, SW2.8
/S4out: R3.1, SW1.5
/S5out: R4.1, SW1.6
/S6out: R5.1, SW1.7
/S7out: U3.1 (CH0), U3.7 (CH6), U5.3
/S8in: U2.6 (-), U2.7, U5.8
/S8out: U3.2 (CH1), U3.8 (CH7), U5.9
/S9out: U6.2, U6.3, U7.4, U7.11
/S10inA: U2.1, U2.2 (-), U6.1, U6.8
/S10inB: R11.2, U1.7, U6.4, U6.11
/S10out: U6.9, U6.10, U8.1, U8.8
/SCK: J1.2, U4.3 (SCK)
/SDI: J1.4, U4.4 (SDI)
/Vt1: R6.2, R8.2, U8.2, U8.3
/Vt2: R7.2, R9.2, U8.9, U8.10
/Write_FB: R10.2, R11.1, U1.6 (-)
GNDA: C1.2, C2.2, C3.2, C4.2, C5.2, C6.2, C7.2, C8.2, C13.2, C14.2, FB2.1, U1.5 (+), U3.9 (DGND), U3.14 (AGND), U4.7 (Vss), U8.4, U8.11
GNDD: C9.2, C10.2, C11.2, C12.2, C15.2, C16.2, C17.2, C18.2, FB1.1, J1.31

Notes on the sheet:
SWITCHES
CROSSBAR ARRAY
DAC TO ADC ANALOG PATH
OPAMP POWER
EXTERNAL POWER SUPPLY CONNECTIONS
FPGA HEADER PINS

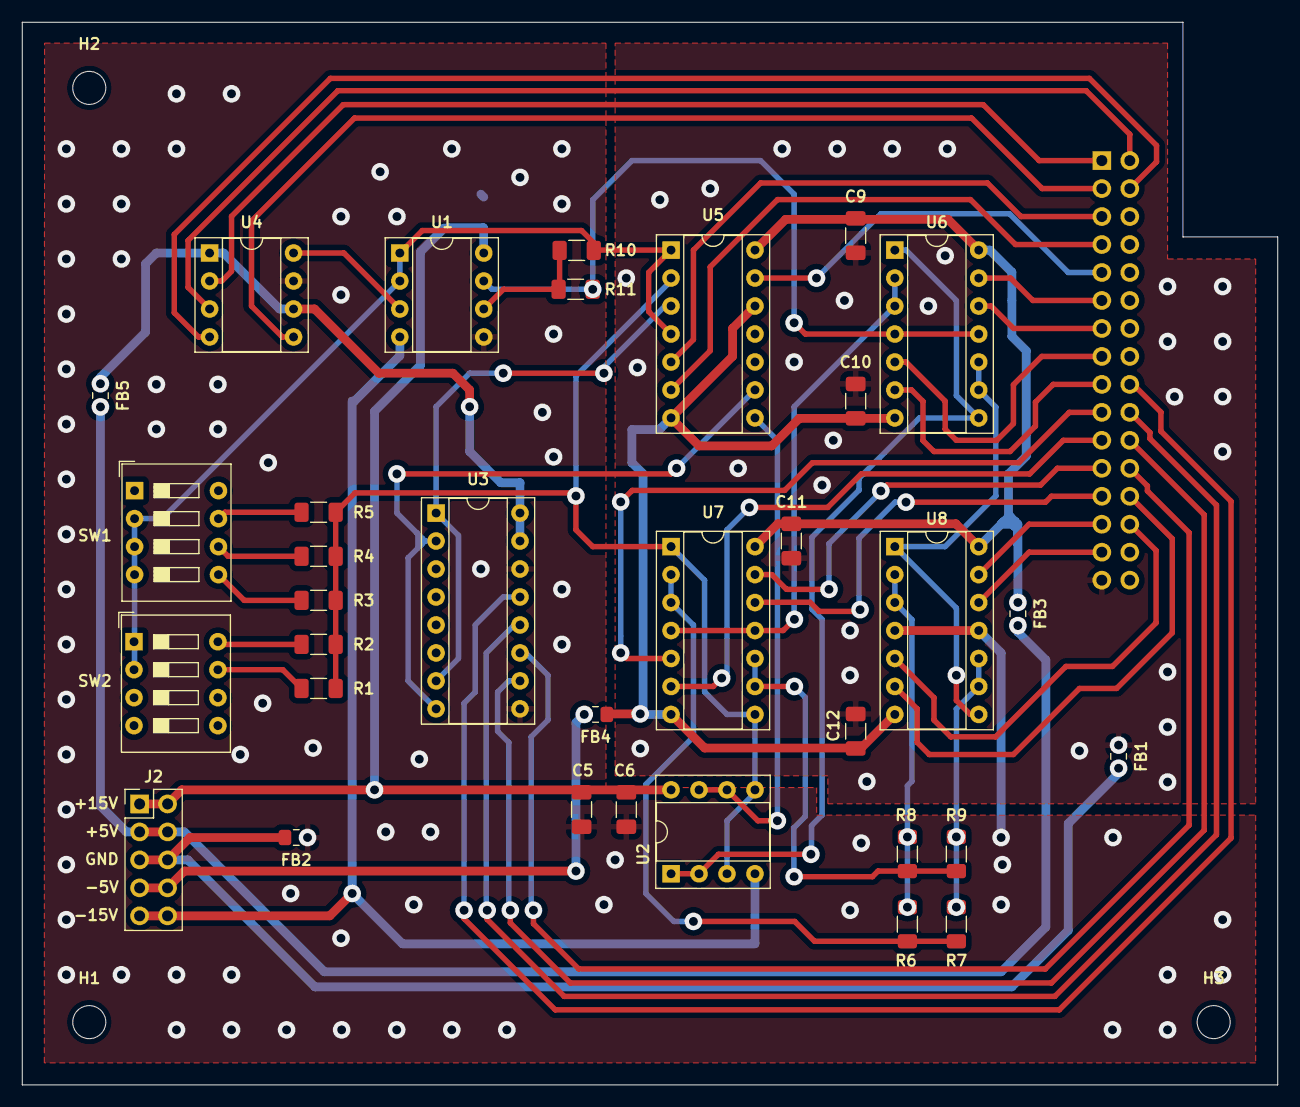
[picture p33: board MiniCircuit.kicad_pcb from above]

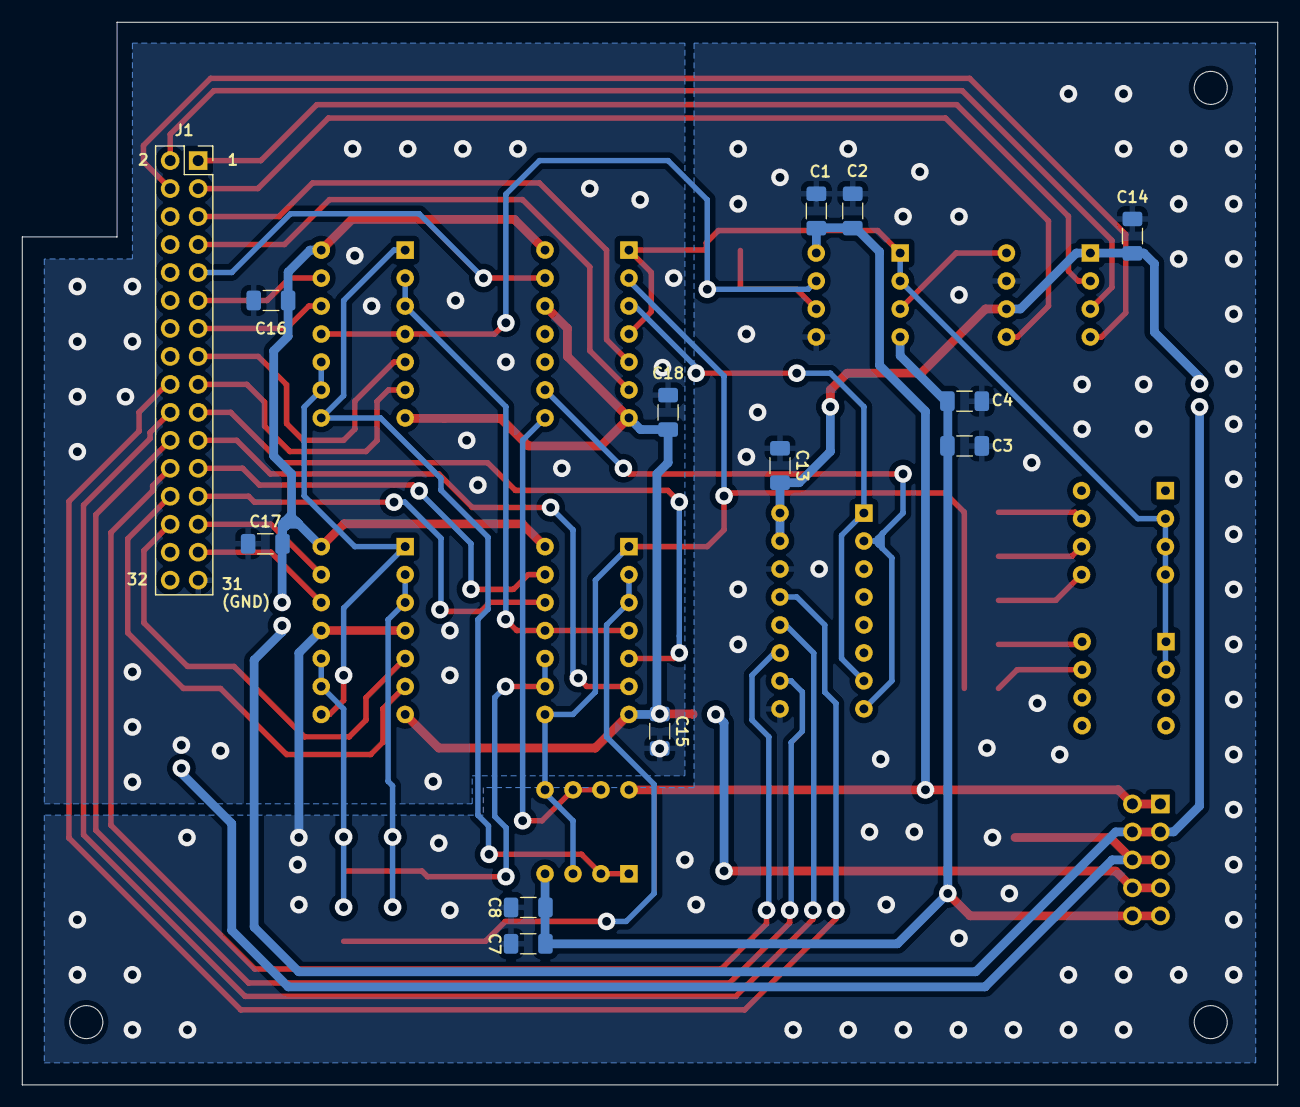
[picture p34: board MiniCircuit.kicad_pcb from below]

Board: 2 copper layers, 114.0 x 96.5 mm, 49 parts (13 on the bottom side), 53 nets.

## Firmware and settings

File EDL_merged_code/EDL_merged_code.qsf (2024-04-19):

# -------------------------------------------------------------------------- #
#
# Copyright (C) 2020  Intel Corporation. All rights reserved.
# Your use of Intel Corporation's design tools, logic functions 
# and other software and tools, and any partner logic 
# functions, and any output files from any of the foregoing 
# (including device programming or simulation files), and any 
# associated documentation or information are expressly subject 
# to the terms and conditions of the Intel Program License 
# Subscription Agreement, the Intel Quartus Prime License Agreement,
# the Intel FPGA IP License Agreement, or other applicable license
# agreement, including, without limitation, that your use is for
# the sole purpose of programming logic devices manufactured by
# Intel and sold by Intel or its authorized distributors.  Please
# refer to the applicable agreement for further details, at
# https://fpgasoftware.intel.com/eula.
#
# -------------------------------------------------------------------------- #
#
# Quartus Prime
# Version 20.1.1 Build 720 11/11/2020 SJ Lite Edition
# Date created = 11:16:07  April 05, 2024
#
# -------------------------------------------------------------------------- #
#
# Notes:
#
# 1) The default values for assignments are stored in the file:
#		EDL_merged_code_assignment_defaults.qdf
#    If this file doesn't exist, see file:
#		assignment_defaults.qdf
#
# 2) Altera recommends that you do not modify this file. This
#    file is updated automatically by the Quartus Prime software
#    and any changes you make may be lost or overwritten.
#
# -------------------------------------------------------------------------- #


set_global_assignment -name FAMILY "Cyclone IV E"
set_global_assignment -name DEVICE EP4CE22F17C8
set_global_assignment -name TOP_LEVEL_ENTITY EDL_merged_code
set_global_assignment -name ORIGINAL_QUARTUS_VERSION 20.1.1
set_global_assignment -name PROJECT_CREATION_TIME_DATE "11:16:07  APRIL 05, 2024"
set_global_assignment -name LAST_QUARTUS_VERSION "20.1.1 Lite Edition"
set_global_assignment -name PROJECT_OUTPUT_DIRECTORY output_files
set_global_assignment -name MIN_CORE_JUNCTION_TEMP 0
set_global_assignment -name MAX_CORE_JUNCTION_TEMP 85
set_global_assignment -name ERROR_CHECK_FREQUENCY_DIVISOR 1
set_global_assignment -name NOMINAL_CORE_SUPPLY_VOLTAGE 1.2V
set_global_assignment -name POWER_PRESET_COOLING_SOLUTION "23 MM HEAT SINK WITH 200 LFPM AIRFLOW"
set_global_assignment -name POWER_BOARD_THERMAL_MODEL "NONE (CONSERVATIVE)"
set_global_assignment -name PARTITION_NETLIST_TYPE SOURCE -section_id Top
set_global_assignment -name PARTITION_FITTER_PRESERVATION_LEVEL PLACEMENT_AND_ROUTING -section_id Top
set_global_assignment -name PARTITION_COLOR 16764057 -section_id Top
set_location_assignment PIN_R8 -to clk
set_location_assignment PIN_B7 -to CS_DAC
set_location_assignment PIN_A4 -to LDAC_DAC
set_location_assignment PIN_B6 -to SCK_DAC
set_location_assignment PIN_A5 -to SDI_DAC
set_location_assignment PIN_L3 -to LED[7]
set_location_assignment PIN_B1 -to LED[6]
set_location_assignment PIN_F3 -to LED[5]
set_location_assignment PIN_D1 -to LED[4]
set_location_assignment PIN_A11 -to LED[3]
set_location_assignment PIN_B13 -to LED[2]
set_location_assignment PIN_A13 -to LED[1]
set_location_assignment PIN_A15 -to LED[0]
set_location_assignment PIN_A12 -to controlmain_readwrite
set_location_assignment PIN_E9 -to controlmain_reset
set_location_assignment PIN_E10 -to Control5
set_location_assignment PIN_E11 -to Control6
set_location_assignment PIN_D9 -to Control7
set_location_assignment PIN_C11 -to Control8
set_location_assignment PIN_F8 -to Control1
set_location_assignment PIN_D8 -to Control4
set_location_assignment PIN_D3 -to Control2
set_location_assignment PIN_C3 -to Control3
set_location_assignment PIN_A3 -to Control9B
set_location_assignment PIN_D5 -to Control10A
set_location_assignment PIN_C6 -to Control10B
set_location_assignment PIN_E6 -to Control9A
set_location_assignment PIN_D12 -to Control_Vt1A
set_location_assignment PIN_D11 -to Control_Vt1B
set_location_assignment PIN_B11 -to Control_Vt2A
set_location_assignment PIN_B12 -to Control_Vt2B
set_location_assignment PIN_B4 -to Control_Hz3B
set_location_assignment PIN_D6 -to Control_Hz3A
set_location_assignment PIN_A6 -to Control_Vt3B
set_location_assignment PIN_B5 -to Control_Vt3A
set_location_assignment PIN_B3 -to Control_Hz1B
set_location_assignment PIN_A2 -to Control_Hz2A
set_location_assignment PIN_A8 -to in_read
set_location_assignment PIN_A7 -to Control_Hz2B
set_location_assignment PIN_C8 -to Control_Hz1A
set_location_assignment PIN_C9 -to CS_ADC
set_location_assignment PIN_F9 -to Din_ADC
set_location_assignment PIN_E8 -to Dout_ADC
set_location_assignment PIN_E7 -to Sclk_ADC
set_global_assignment -name QIP_FILE uart_jtag/synthesis/uart_jtag.qip
set_global_assignment -name VERILOG_FILE EDL_merged_code.v
set_global_assignment -name VHDL_FILE ADC_DAC_control.vhd
set_instance_assignment -name PARTITION_HIERARCHY root_partition -to | -section_id Top

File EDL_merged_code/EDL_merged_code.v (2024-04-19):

//Deshapande Varad Shailesh
//21d070024
//Jan-April 2024 @ IIT Bombay

module EDL_merged_code(
		input  wire     clk,
		
		output reg[7:0] LED,
		
		output wire SCK_DAC,		//out
		output wire CS_DAC,			//out
		output wire reset_DAC,		//out
		output wire SDI_DAC,		//out
		output wire LDAC_DAC,		//out
		output wire reset_ADC,	//out
		output wire Din_ADC,	//out
		input wire Dout_ADC,	//in
		output wire CS_ADC,	//out
		output wire Sclk_ADC,	//out
		input wire ch_display_select,	//in
		
		
		output reg 	controlmain_reset,
		output reg 	controlmain_readwrite,
		
		output reg  Control1,
		output reg  Control2,
		output reg  Control3,
		output reg  Control4,
		output reg  Control5,
		output reg  Control6,
		output reg  Control7,
		output reg  Control8,
		output reg  Control9A,
		output reg  Control9B,
		output reg  Control10A,
		output reg  Control10B,
		output reg  Control_Vt1A,
		output reg  Control_Vt1B,
		output reg  Control_Vt2A,
		output reg  Control_Vt2B, 
		output reg  Control_Vt3A,
		output reg  Control_Vt3B,
		
		output reg  Control_Hz1A,
		output reg  Control_Hz1B,
		output reg  Control_Hz2A,
		output reg  Control_Hz2B, 
		output reg  Control_Hz3A,
		output reg  Control_Hz3B	
		
    );
	 	
	 

	 

	 
	 //measured_val, MSB_ADC are for ADC
	 reg[9:0] measured_val_CH0;
	 initial begin
	 measured_val_CH0 <= 10'b0000000000;	
	 end

	 reg[9:0] measured_val_CH1;
	 initial begin
	 measured_val_CH1 <= 10'b0000000000;	
	 end
	
    
    reg[1289:0] measured_values_CH1_single_vector;	 
	 initial begin
	 measured_values_CH1_single_vector <= 1290'b000000000000000000010000000010000000001100000001000000000000000000000100000000100000000011000000010000000000000000000001000000001000000000110000000100000000000000000000010000000010000000001100000001000000000000000000000100000000100000000011000000010000000000000000000001000000001000000000110000000100000000111100000001110000000000000000000100000000100000000011000000010000000000000000000001000000001000000000110000000100000000000000000000010000000010000000001100000001000000000000000000000100000000100000000011000000010000000000000000000001000000001000000000110000000100000000000000000000010000000010000000001100000001000000001111000000011100000000000000000001000000001000000000110000000100000000000000000000010000000010000000001100000001000000000000000000000100000000100000000011000000010000000000000000000001000000001000000000110000000100000000000000000000010000000010000000001100000001000000000000000000000100000000100000000011000000010000000011110000000111000000000000000000010000000010000000001100000001000000000000000000000100000000100000000011000000010000000000000000000001000000001000000000110000000100000000000000000000010000000010000000001100000001000000000000000000000100000000100000000011000000010000000000000000000001000000001000000000110000000100000000111100000001110000000111;

	 end
	
	
	 
	 reg store_trigger;
	 initial begin
	 store_trigger <= 1'b0;	
	 end	 
	 
	 reg[31:0] sample_counter;
	 initial begin
	 sample_counter <= 32'd0;	
	 end
	 
	 integer sample_index;
	 initial begin
	 sample_index <= 0;
	 end
	 
	 reg start_sampling;
	 initial begin
	 start_sampling <= 1'b0;	
	 end

	 reg sending;					//1 when sending data to laptop, and 0 when confirming if sent data is received. 
	 initial begin
	 sending <= 1'b1;	
	 end
	 
	 reg received_at_laptop;
	 initial begin
	 received_at_laptop <= 1'b0;	
	 end
	 
	 
	 reg MSB_ADC;
	 initial begin
	 MSB_ADC <= 1'b0;
	 end

	 reg CH0_done;
	 initial begin
	 CH0_done <= 1'b0;
	 end
	 
	 reg sampling_complete;
	 initial begin
	 sampling_complete <= 1'b0;
	 end	 
	 
	 // push_val_to_DAC, pulse_value, pulse_out_from_DAC are for DAC
	 reg push_val_to_DAC;
	 initial begin
	 push_val_to_DAC <= 1'b0;	
	 end		
	 
	 reg[11:0] pulse_value;
	 initial begin
	 pulse_value <= 12'b0;	
	 end	

	 reg[11:0] pulse_out_from_DAC;
	 initial begin
	 pulse_out_from_DAC <= 12'b0;	
	 end	  	 
	 
	 
	
	
	 
	 
	 //jtag uart signals

    wire        jtag_uart_cs;
    wire        jtag_uart_addr;
    wire                reset;
	 
	 
    reg        jtag_uart_write;
	 initial begin
	 jtag_uart_write <= 1'b0;	
	 end
	 
    reg [31:0] jtag_uart_wdata;
	 initial begin
	 jtag_uart_wdata <= 32'b00000000000000111000000000000000;	
	 end
	 
	 reg        jtag_uart_read;
	 initial begin
	 jtag_uart_read <= 1'b1;	
	 end
	 
    reg [31:0] jtag_uart_readdata;
	 
	 
	 //logic flow signals
	 
	 reg[17:0] control_signals;
	 initial begin
	 control_signals <= 18'b00000000000000000;	
	 end		
	 
	 reg[2:0] control_signals_received;
	 initial begin
	 control_signals_received <= 3'b000;
	 end
	 
	 reg[5:0] pulse_width;
	 initial begin
	 pulse_width <= 6'b000000;
	 end
	 reg pulse_width_received;
	 initial begin
	 pulse_width_received <= 1'b0;
	 end
	 
	 reg[31:0] counter;
	 initial begin 
	 counter <= 32'd0;
	 end
	 
	 parameter t1 = 32'd50;
	 parameter t2 = 32'd400000000;			//8s given for getting the pulse value

	 integer count_sends;
	 initial begin
	 count_sends <= 0;	
	 end	
	 
	 integer count_wait;
	 initial begin
	 count_wait <= 0;	
	 end
	 
	 reg reading;
	 initial begin
	 reading <= 1'b0;	
	 end	
	 
	 reg writing;
	 initial begin
	 writing <= 1'b0;	
	 end		 
	
	 reg[31:0] state;								//0: start, 1: read pulse value, 2: show ADC value
	 initial begin									
	 state <= 32'd0;
	 end
	 
	 integer state_integer;								//0: start, 1: read pulse value, 2: show ADC value
	 initial begin									
	 state_integer <= 0;
	 end
	 
	 reg[3:0] both_transferred;				//to ensure that both bytes have been sent/received
	 initial begin									//can take values: 0101(none),1101(only MSB done), 0100(only LSB done), 1100(both MSB LSB done)
	 both_transferred <= 4'b0101;
	 end

	 
		//some permanent jtag signals
		assign reset = 1'b0;
		assign jtag_uart_cs = 1'b1;
		assign jtag_uart_addr = 1'b0;
		

		always @(posedge clk) begin			//main process
		
		
		if(sample_counter <= 32'd127) begin
			if (store_trigger) begin
			   sample_index <= sample_counter;
				measured_values_CH1_single_vector[10*(sample_index+1) +:10] <= measured_val_CH1;
			end
		end
		
		if(sample_counter >= 32'd127) begin
			sampling_complete <= 1'b1;
		end
		
		
		
		
		
		
		
		//the control block starts here
		
		




			
		
			if (state == 32'd0) begin
				counter <= counter + 1;
				if(counter == 32'd50) begin
					state <= 32'd1;
					counter <= 32'd0;
				end
			end
			
			if (state == 32'd1) begin
				reading <= 1'b1;
				writing <= 1'b0;
				
				if (both_transferred == 4'b1100) begin
//					push_val_to_DAC <= 1'b1;
					state <= 32'd8001;			//32'd5003
					both_transferred <= 4'b0101;
					reading <= 1'b0;
				   writing <= 1'b0;
					received_at_laptop <= 1'b0;
				end	
			end
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

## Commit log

2024-03-21 Initial Commit with MAX4737 Switches. Branch will now be used to change switches to CD4066
    [AD744JRZ-REEL7.step, ADS7223SRHBT.step, CD4066BE.SchLib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]
2024-03-21 Changed Schematic to include CD4066 instead of MAX4737. Design Constraints, Routing and Layout remaining
    [MiniCircuit.kicad_pcb, MiniCircuit.kicad_sch]
2024-03-21 PCB Done, only final touch and verification necessary
    [MiniCircuit.kicad_pcb, MiniCircuit.kicad_sch]
2024-03-21 All errors and warnings rectified. Silkscreen contents added.
    [MiniCircuit.kicad_pcb]
2024-03-21 PCB Complete. Self verification left.
    [MiniCircuit.kicad_pcb, MiniCircuit.kicad_sch]
2024-03-22 Verified PCB, near final testing
    [MiniCircuit.kicad_pcb, MiniCircuit.kicad_sch]
2024-03-22 Modified as per final component footprints
    [MiniCircuit.kicad_pcb, MiniCircuit.kicad_sch]
2024-03-22 Added final touches
    [MiniCircuit.kicad_pcb, MiniCircuit.kicad_sch]
2024-03-22 Changed some reference text thickness to match Design Constraints (altho, won't be printed)
    [MiniCircuit.kicad_pcb]
2024-03-22 Revised PCB as told by PCB Lab
    [MON08-B_Cu.gbr, MON08-Edge_Cuts.gbr, MON08-F_Cu.gbr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]
2024-03-29 presentations and schematic
2024-03-31 Created FinalPCB Project. All routing except control lines done.
    [FinalCircuit.kicad_pcb, FinalCircuit.kicad_sch]
2024-03-31 Almost all connections done. Digital traces seem too long at the moment.
    [FinalCircuit.kicad_pcb, FinalCircuit.kicad_sch]
2024-04-01 all FPGA files before combining
    [jtag_uart.csv]
2024-04-01 Final PCB all routing done, 0 errors. Verification left
    [FinalCircuit.kicad_pcb, FinalCircuit.kicad_sch]
2024-04-01 Found an error in LM6172 connection. Routing of that is left.
    [FinalCircuit.kicad_pcb, FinalCircuit.kicad_sch]
2024-04-01 Final PCB Done. Resistive Crossbar PCB Done. Verification left.
    [FinalCircuit.kicad_pcb, FinalCircuit.kicad_sch, ResistiveCrossbar.kicad_pcb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]
2024-04-02 Stage 2 verification done. Holes and connectors aligned. Final verification at PCB Lab left.
    [FinalCircuit.kicad_pcb, ResistiveCrossbar.kicad_pcb, ResistiveCrossbar.kicad_sch]
2024-04-02 Some more alignments completed. Verification done again. Final order left.
    [FinalCircuit.kicad_pcb, ResistiveCrossbar.kicad_pcb]
2024-04-02 Some minor silkscreen changes and constraints.
    [FinalCircuit.kicad_pcb, ResistiveCrossbar.kicad_pcb]
2024-04-03 PCB Layout and routing of all PCBs added as per the final accepted version by the PCB Lab.
    [Copper_bottom.gbr, Copper_top.gbr, Drill.drl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]
2024-04-09 comm + DAC + ADC all working
2024-04-09 fully functional FSM with comms + ADC + DAC
2024-04-10 building up the array transfer
    [EDL_merged_code.smp_dump.txt]
2024-04-11 control signals tried on PCB
    [EDL_merged_code.smp_dump.txt]
2024-04-11 fixed control lines to PCB with crossbar PCB and elementary ADC
    [EDL_merged_code.qsf]
2024-04-13 fully working oscilloscope with correct communication to laptop through jtag uart
    [EDL_merged_code.smp_dump.txt]
2024-04-14 sampling of ADC and transmission to PC correct, no controls
    [EDL_merged_code.v]
2024-04-14 FSM fully ready, need to map control signals and pulse width, get both channels to sample, let switches be se first and then have the DAC send o/p
2024-04-19 PCB Enclosure
    Size of .stp file was too large to be added to GitHub
    [Enclosure_Fusion360.dxf]
2024-04-19 Final FPGA code commit, with end-to-end functionality inclusive of GUI
    [EDL_merged_code.smp_dump.txt, jtag_uart.csv]
2024-04-19 Rename PCB.pdf to EDL PCB Documentation.pdf
2024-04-19 Delete Components Library directory
    This folder was used in the ideal circuit schematic and ideal circuit pcb which is not used here, hence deleting
    [AD744JRZ-REEL7.step, ADS7223SRHBT.step, CD4066BE.SchLib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]
